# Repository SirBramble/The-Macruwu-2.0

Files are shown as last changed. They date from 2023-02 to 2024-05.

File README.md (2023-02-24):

# The Macruwu
The macro pad for all! (well, at least, if you can understand the Clusterfuck posted here)
The Firmware is based on the Arduino Pico Core by earlephilhower https://github.com/earlephilhower/arduino-pico. 

**This is only a brief overview** The full documentation and instructions can be found in the "Documentation"-folder.

## Components used

I went with the RP2040 based board from seeed studio. It has a fast chip, offers integrated USB support and is only about 6€. However, it has limited GPIO pins. So if you want to build your own, I would recommend using I/O Expanders or something similar. Another option would be to use a raspberry Pi with a RP2040. This Board beaks out most of the RP2040 Pins and has Options for Wi-Fi.

In order to try out different Key switches and keep the Macruwu modular, I decided to use hot swap sockets. They aren’t to expensive, if you order them for AliExpress (about 1\$/10psc). But beware, when soldering. If your board manufacturer decides to give you the shit coating on your Pads, prepare for heavy flux use.

For the I/O Expanders I used the PCA9555 from NXP. They conveniently don’t need a lot of setup and are automatically set to INPUT_PULLUP. The detailed Addressing scheme and co can be found in the Datasheet. But, as per usual nowadays, the I/O expanders are sold out. So, you might want to look for them somewhere else, or find a suitable replacement. But if you can find them, I can recommend the NXP Expanders. They need minimal to no Software Setup and I haven't had a dead one so far.

The level shifter (TXU0104PWR) is a cheap option I got from Mouser. It has 4 channels it can shift and is enough for the two 5V I²C Lines and the neopixel line.

The keyswitches were purchased for AliExpress and some smaller Keyboard parts suppliers. I like clicky switches, so I went for the Gateron greens. However, I cannot recommend them. They sound quite hollow and scratchy. Could maybe fixed with some lube *gigidy*, but it’s not really worth the trouble. 
If you want some really clicky Keyswitches, that will any the hell out of anybody in a 30km Radius, you could go for the Kailh Low profile Chock whites. My, extremely pissed of, fellow student can confirm. However, be aware that they can not be used with relegendable keycaps.
## How to compile

### With the Arduino IDE 2.0
#### Macruwu
First download the Code either from the repo or via the release tab. Put it in a folder and open the ```Macruwu_OS.ino``` file.

In order to compile the Code, you need to install the Arduino Pico core. There is a Tutorial on how to do this on earlephilhowers GitHub. You will also need the Adafruit SPIFlash Library. It can be downloaded via the Library Manager. The rest should be included in the Pico Core.
If you get Library conflicts, I'm afraid you're on you’re own. I somehow got it to compile and haven’t touched my setup since. No Idea why it suddenly worked, but the only thing I can recommend, is to back up your libraries and start fresh.

EDIT: If you get a Library conflict, you may want to look for other Bugs. Sometimes the Arduino IDE shows this message, just to inform you, that it has used a certain Library. However, your Code may not compile due to another error.

Also remember to change the USB Stack to the Adafruit TinyUsb Stack via Tools->USB Stack.
If you want to use the inbuilt Flash as a drive, you also have to allocate Memory under Tools->Flash Size. The first time you allocate Memory, you will have to format it. Just doing it in Windows should be fine.
P.s. The flash drive code is more or less copied from Adafruit. sorry, I was lazy...

#### Bluetuwu
First download the Code either from the repo or via the release tab. Put it in a folder and open the ```Bluetuwu_OS.ino``` file.

To Compile the Code you need to install the ESP32 Arduino Core from Espressif. After you installed this, you can just upload with the standard Settings.

### With PlatformIO
Well... I have no Idea, but let me know, if you find out.

## How to use (isch...)

The Macruwu OS is divided in to several Files for maximum ```'someFuckingShit' is not defined did you mean 'goFuckYourself'?```

### With macroLayout.txt

NOTE: The first time you start the Macruwu, you might have problem, with it crashing. This may be caused by the File not being present in the Flash directory. You may have to disable the ```readFile```-function in the ```Keyboard::init```-function in ```Keyboard.cpp``` and upload the File first. Then reenable the function and it should run.

The Layout can be set with several Commands. ```Layer x: ``` sets the Layer under which the Buttons will be accessible. ```Button x: {string}``` sets the Button and is followed by the string, that will be printed by the keyboard. Remember to leave a space between ```:``` and ```{string}```. This is due to the way that the file gets read. The Character straight after the ```:``` will be ignored.

So far, most characters will be interpreted correctly, however ```<``` and ```>``` have a special Meaning. They press the left and right arrow keys respectively. Verry useful for Macro pads that print code with a lot of Brackets. Other functions have not yet been implemented, but feel free to add them in the ```Keyboard.cpp``` under ```Keyboard::interpet```.

In order to read the file from the Flash in to the Data structure you want to run the ```readFile```-function at least once. I recommend running it once in ```setup()``` and then running it each time the file is changed. this can be done with:
```
if(Macruwu.fsChanged()){
    Macruwu.readFile();
  }
```

In order to run the commands that have been set in the Data structure you will have to run the ```interpret(layer, button)```-function.

### With Hardcoded Mapping
The Keymapping can be set in the ```Mapping.cpp```.

In order to write something over USB, you can use ```Keyboard1.write("something");``` But this only works for most normal characters like letters and sometimes other specialty symbols. You'll have to try it out. Things like Brackets or things that use function keys, will have to be set up manually. This can either be done, by sending the commands via the Tiny USB library directly, or by adding a new function to the Keyboard class. But look through the Keyboard class, as I may add more functions in the future.

**Word of Warning:** If you do not have a US Keyboard, be prepared for some HID Code treasure hunting. I haven’t found a way to change the layout, so you either have to find a Layout and redefine all the keys in the library, or just try and hope you find what you need. If you have a German Keyboard layout set, you can reference the code for some mappings.

## Bugs
Yes

## Further documentation
I recommend reading the documentation by earlephilhower https://github.com/earlephilhower/arduino-pico. It´s a far better than this clusterfuck, but feel free to look through the code.

And in case you didn't read the first 3 lines, you can find more documentation in the "Documentation"-folder.

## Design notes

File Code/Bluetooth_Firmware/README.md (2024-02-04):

# README Bluetooth Firmware

## Compilation instructions

First you will need the esp32 Core by Espressif.

**IMPORTANT:** You need to install Version *2.0.11*. The newer Versions feature a different String type in the *begin* function. This will cause compilation errors.

### Upload settings

In order of appearance:

- **Board:** "XIAO_ESP32C3"
- **USB CDC On Boot:** "Enabled"
- **CPU Frequency** "160MHz (WiFi)"
- **Core Debug Level:** "None"
- **Erase All Flash Before Sketch Upload:** "Disabled"
- **Flash Frequency:** "80MHz"
- **Flash Mode:** "QIO"
- **Flash Size:** "4MB (32Mb)"
- **Partition Scheme:** "Default 4MB with spiffs (1.2MB APP/1.5MB SPIFFS)"
- **Upload Speed:** "921600"

## Config Options

 In ```BleKeyboard bleKeyboard("Macruwu", "FG Labs", 69);``` the *Device Name*, *Manufacturer* and *Initial Battery Level* can be set.

In the ```receiveEvent``` function new/custom I²C commands can be added.

```c
while(Wire.available()){
reportID = Wire.read();
switch(reportID){
  case RID_KEYBOARD:
    tmp->modifiers = Wire.read();
    tmp->keys[0] = Wire.read();
    tmp->keys[1] = Wire.read();
    tmp->keys[2] = Wire.read();
    tmp->keys[3] = Wire.read();
    tmp->keys[4] = Wire.read();
    tmp->keys[5] = Wire.read();
    break;
  case 15:
    softDisableFlag = Wire.read();
    if(softDisableFlag != 0) softDisableFlag = true;
    break;
  default:
    Wire.read();
    break;
}
```

As of creation of the README, 2 functions have been implemented.

- Function 1 (ReportID = 1)
  - Reads a Key report
  - Order:
    - modifier: 1 byte
    - keys: 6 bytes
- Function 2 (ReportID = 15)
  - Sends ESP in to deep sleep
  - This is used to save power, when the Keyboard is connected and registered via USB HID.
- default (ReportID = *none of the above*)
  - voids the I²C buffer

To add a function

- assign a ReportID
- add a new case to the switch

## Troubleshooting

- Macruwu is connected, but doesn't send Keycodes
  1. Unpair Keyboard from Host
  2. power cycle the Keyboard
  3. Re-pair the Keyboard
- Macruwu can't be found
  1. Toggle the power (quick ON/OFF flipping of the power switch)
- ESP stuck in boot loop
  1. Sorry to hear that :(
  2. Make sure the battery board is powered on correctly
     - If the Voltage converter is buzzing, you have a power problem
       - The Battery could be flat (or close to)
       - The board is not turned on properly (use the power toggle switch)
  3. Check the upload parameters
     - Try changing the *Flash Frequency* to *40MHz*

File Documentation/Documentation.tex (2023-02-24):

\documentclass[english, 12pt]{scrartcl}
\usepackage{caladea}
%\usepackage{gfsartemisia-euler}
\usepackage[
a4paper,
left=2.5cm,
right=2.5cm,
top= 2cm,
bottom = 2.5cm,
footskip = 1.5cm
]{geometry}
\usepackage{fancyhdr}
\usepackage[english]{babel}
\usepackage[T1]{fontenc}
\usepackage{graphicx,float}
\graphicspath{ {./images/} }
\usepackage{wrapfig}
\usepackage{caption}
\usepackage{pdfpages}
\usepackage{makecell}
\usepackage{subfiles}
\usepackage{enumitem,amssymb}
\usepackage{lastpage}
%\usepackage{amsmath}
\usepackage{esint}
\usepackage{blindtext}
\usepackage{hyperref}
\hypersetup{
	colorlinks=true,
	linkcolor=black,
	filecolor=magenta,      
	urlcolor=cyan,
	pdftitle={The Macruwu},
	pdfpagemode=FullScreen,
}
\urlstyle{same}
\usepackage[inkscapeformat=png]{svg}
\usepackage{tikz}
\usetikzlibrary{shapes.geometric, arrows}
\usepackage[
% school,
simplified
]{pgf-umlcd}
\usepackage{listings}
\usepackage{color}
\definecolor{listinggray}{gray}{0.92}

\pagestyle{fancy}

\title{\fontfamily{}\selectfont The Macruwu}
\author{Bramble}
\date{}
\begin{document}
	\maketitle
	
	\tableofcontents
	\newpage
	\section{Incentive}
	My handwriting is something any doctor would be proud of. My teachers, however, were not so enamoured with my writing prowess, often deducting grades for sheer illegibility. So when I went to uni, I started taking notes digitally. First, I tried my luck with OneNote and a digital pen, hoping somehow it would improve my notetaking-ability. But when that inevitably failed, I switched to Word. For those who have never tried, writing equations in Word is a pain in the back side. It takes ages and especially when equations get more complex, it's a nightmare to try and get the $e^{x}$ to go, where you want it to go.\\
	So I switched once more.I went for Markdown with inline $L^AT_EX$. Markdown is a markup language that can easily run in a browser and like $L^AT_EX$ it's "what you mean is what you get". It has simple syntax, making it easy to learn, but also supports inline $L^AT_EX$, which is very useful when writing equations. The hoster we (my friends and I) use also supports multiple people working on the same document in real time, which makes taking notes a lot faster and also allows one person to be sketching graphs and the like, while the rest of us try our best to keep up with the professor.\\
	But even with Markdown and multiple people writing at the same time, it just took too long and we sometimes missed some important notes.\\

	\begin{wrapfigure}{r}{0.25\textwidth}
		\vspace{-0.8cm}
		\centering
		
		\caption{Macropad v0.1}
	\end{wrapfigure}
	\noindent One afternoon I therefore cobbled together my first macro pad out of some Cherry switches and a Teensy I had lying around. It was extremely botched and had no fancy features to speak of, but it worked. That got me hooked. Even with just eight extra keys, I was able to write a lot faster. So I went back to the drawing board and started designing what was to become the Macruwu.
	\section{Requirements}
	For this macropad to be of any use to me, it needed to fulfil certain requirements.
	\begin{itemize}
		\item It needed to be compatible with any system. This meant it needed to work, no matter which computer I plugged it in to. This also meant that I couldn't rely on any software that had to be running in the background.
		\item It should be able to type out any key combination that would also be possible on a normal keyboard. This would make it universally useable for practically any software, because almost all software can be controlled easily with shortcuts from a keyboard.
		\item It must not hinder my workflow. This means that using the Macruwu should always be faster than typing out the command or character strings by hand.
		\item It needed to be fast. I wanted as little delay as possible, so that long strings of characters could be printed quickly. For complex equation presets a maximum delay of about 300-400ms would be optimal.
		\item Mappings should be changeable on the fly. If, for example, a certain equation were to show up consistently in the lecture, it should be possible to assign that equation to a key quickly and easily.
		\item It should be expandable. If 32 keys aren't enough or if I want to add some kind of other interface device or expansion module, it should be possible to interface it with the Macruwu.
		\item It MUST have RGB. I could try and think up some reason for why it's necessary to have RGB, but I just want RGB uwu.
		\item It should be affordable. The goal for this project was to stay under 70€ per unit.
		\item It should be repairable. For me this meant, creating options for most kinds of mechanical keyswitches. If a switch breaks or if I want to later replace them with different ones, it should be easy to just rip´em out and stick in some ones.
	\end{itemize}
	\newpage
	\section{Choices of component}
	\subsection{Microcontroller}
	For the microcontroller, I chose the seeed studio RP2040. It´s a small board, even smaller, than a Teensy, but it allows you to configure it as an HID with very little effort. It's also very fast and has a humongous 2MB of flash, which can also be configured as a mountable flash drive. It doesn't have a lot of pins but it does have a number of broken out connections, namely two I$^2$C lines, an SPI bus and even a UART port if you need it. And USB-C is just the cherry on top (no pun intended).\newline
	If you want to learn more, you can check out the \href{https://wiki.seeedstudio.com/XIAO-RP2040/}{Seeed Wiki}. This is good to get you started with the microcontroller, but if you want more information on the programming side, you should check out Earle Philhowers Arduino Pico \href{https://github.com/earlephilhower/arduino-pico}{GitHub} and \href{https://arduino-pico.readthedocs.io/en/latest/}{documentation}.
	
	\subsection{I/O expanders}
	In order to read the keyswitch inputs some kind of I/O expander was needed. I just went for the cheapest I could find on Mouser that was still in stock. It turned out to be the \href{https://www.mouser.de/datasheet/2/302/PCA9555-1127545.pdf}{PCA9555D}, a double 8-bit I/O expander that can be read via I$^2$C. It offers internal pull-up resistors, which was a nice bonus, meaning I didn't have to add them to the design. However, bear in mind that you might have to add some to your design if you want to use a different I/O expander.
	
	\subsection{Level shifter}
	The RP2040 is a 3.3V microcontroller. In order to use 5V logic devices, a level shifter is needed. This is optional, however. If you don't plan on using the NeoPixels or 5V I$^2$C devices, you can just leave it out. At first I used the \href{https://www.ti.com/lit/gpn/txu0104}{TXU0104PWR} which is a unidirectional chip. This works great for the NeoPixels, but won't work for the 5V I$^2$C due to this being a bidirectional protocol. However Texas Instruments offers a pin-equivalent bi-directional chip, the \href{https://www.ti.com/lit/gpn/lsf0204-q1}{LSF0204-Q1}. I haven't tested it so far, but the datasheet indicates that this should be a drop-in replacement.
	
	\subsection{RGB goodness}
	In order to satisfy my endless need for funny blinky lights, I picked up some \href{https://de.aliexpress.com/item/1005003636607308.html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}{SK6803 MINI-Es} from AliExpress. They come in 3mA and 12mA versions. In order to not overtax the USB power, I'd recommend getting the 3mA version. They should be more than bright enough. If you want to burn out your retinas, you can also go for the 12mA version, but bear in mind that you may run into Voltage drops when running them at the full 12mA.\newline
	One of the most useful features of the SK6803 MINI-Es is their ability to be mounted through a cutout in the PCB, making them sit flush with the surface. This allows the use of most switches. They also have a identical addressing scheme to standard NeoPixels and can be controlled by the Adafruit Neopixel library.
	
	\subsection{Hot-swap sockets}
	In order to change keyswitches without having to solder, some sort of hot-swap socket is needed. I chose \href{https://keycapsss.com/keyboard-parts/parts/49/kailh-hotswap-pcb-sockets-10-pcs?c=11}{Kailh hot-swap sockets}. They're easy to solder and work a lot better than the push-in ones you might find on commercial hot-swap boards. They also come in versions for MX- and Choc-style keyswitches.
	
	\subsection{Keyswitches}
	This is pure preference. I love clicky keys, so I went for the clickiest (reasonably priced) keys I could find. The \href{https://de.aliexpress.com/item/32980039972.html}{Gateron greens} are a very affordable option for MX style keys and are quite clicky. If you want maximum click for a bit more cash, you can check out the \href{https://keycapsss.com/switchestester/switches/65/kailh-low-profile-choc-switches?c=9}{Kailh whites}. They provide maximum click and are guaranteed to annoy the living heck out of most sane people. Needless to say I absolutely love them.\newline
	If you prefer not to make everyone within a 30Km radius go completely insane, you can also choose a tactile or linear switch. Both the Gateron and Kailh keys offer those options. If you want to fall in to a very deep rabbit hole, you can also look up keyswitches on YouTube. Trust me, it's worth it.
	
	\subsection{Keycaps}
	Now here there are several options. You can 3D-print your keycaps on a resin printer or print flat ones on an FDM printer and label them afterwards. You can get quite creative with custom keycaps. If you don't want to print your own, \href{https://de.aliexpress.com/item/1005003047698548.html}{relegendable keycaps} are always an option and the one I went for. A printable template for the keycap inlays is in the main GitHub repository.
	
	\subsection{I$^2$C Jacks}
	To connect the Macruwu to other input devices I used a \href{https://keycapsss.com/keyboard-parts/parts/54/2x-trrs-jacks-3.5mm?c=11}{3.5mm 4-pin headphone jack}. This breaks out 3.3V, GND, SCL, SDA and offers the option to use a wide variety of fancy cables.
	\newpage
	\section{Hardware}
	
	\subsection{Full schematics}
	\begin{figure}[H]
		\centering
		
		\caption{Sheet 1 of the Macruwu}
	\end{figure}
	\begin{figure}[H]
		\centering
		
		\caption{Sheet 2 of the Macruwu}
	\end{figure}
	\begin{figure}[H]
		\centering
		
		\caption{PCB frame 1 of the Macruwu}
	\end{figure}
	\begin{figure}[H]
		\centering
		
		\caption{PCB frame 2 of the Macruwu}
	\end{figure}
	\begin{figure}[H]
		\centering
		
		\caption{PCB frame 3 of the Macruwu}
	\end{figure}
	\begin{figure}[H]
		\centering
		
		\caption{PCB frame 4 of the Macruwu}
	\end{figure}
	\begin{figure}[H]
		\centering
		
		\caption{PCB frame 5 of the Macruwu}
	\end{figure}
	
	\subsection{Soldering tips}
	SMD soldering is a pain, but in this case necessary. If you've never soldered SMD before or if it's been a while, here are some tips:
	\begin{itemize}
		\item Start with the smallest components. I'd recommend starting with the SMD capacitors. They're really fiddly, but are good for practice, especially if you haven't soldered SMD before. If you mess up, they're also easy to remove letting you try again. And if you manage to solder all the capacitors, the rest shouldn't be a problem.\newline
		\textbf{NOTE:} When soldering the capacitors, leave out the ones near the ICs and do them later. They might get in the way when soldering the ICs.
		\item When soldering the ICs, start by tinning a single pad. Once you've tinned one pad, heat it up and push the IC in to place. Then you can solder the rest of the connections.
		\item Use flux. It's not strictly necessary but it does help a lot, especially when using lead-free solder. If you find yourself getting a lot of bridges or cold solder joints, give flux a try. It really does help. I personally use the \href{https://www.amazon.de/FELDER-L%C3%B6tfett-L%C3%B6tmittel-Solder-L%C3%B6tpaste/dp/B01822CUO6}{flux paste you get in those small tins} but any flux is better than none.
		\item Have some solder wick lying around. If you find yourself unable to separate a bridge on an IC, you'll want solder wick. Ideally apply some flux to the wick, place it on the solder joints you want to disconnect and press your soldering iron on top. This should pull any unnecessary solder in to the wick.\newline
		\textbf{NOTE:} Don't pull the solder wick around the connection or PCB. This will scrape away the solder mask and may expose or cut traces. I found that out the hard way...
		\item When soldering in the hot-swap sockets and RGB LEDs, make sure they're properly soldered to the board. Ground pads especially tend to result in cold solder joints. Use flux and check your connections with a multimeter. For the hot-swap sockets you can increase the temperature to about 370-400°C, but try not to keep the iron on there for too long if you do. With the LEDs I'd recommend not going above 360°C because if you do, they might break. I haven´t had this happen before, but bear this in mind.
		\item Clean your board after soldering. You can use isopropanol or similar non conducting cleaning liquids. This is to prevent corrosion and general stickiness from the flux.
	\end{itemize}
	
	\section{Macruwu Firmware}
	This firmware is based on Earle Philhowers \href{https://github.com/earlephilhower/arduino-pico}{Arudino Pico} and includes some Adafruit libraries. Therefore, make sure to install them before trying to flash this code.
	\subsection{Structure}
	\textbf{NOTE:} I'm not studying computer science so this diagram may not be up to standard. However, I hope it gives you a brief overview of how the code is structured. This will be updated with code updates (hopefully).\newline
	\begin{minipage}{\linewidth}
		\centering
		\resizebox{0.5\textheight}{!}{\input{Classes/Keyboard}}
	\end{minipage}
	\newline
	\newline
	The basic idea of this code is to divide everything up in to separate modules that interface with one aother. This takes a bit more effort to try and get the separate modules working together, but once it's set up, it's a lot easier to tweak.
	\subsubsection{Layer class}
	OK, so now lets go over the structure and start at the bottom. The \textit{Layer} class has a vector of strings. This stores all the plaintext commands associated with a certain button. So a \textit{Layer}-object has several buttons.
	\subsubsection{Keymap class}
	The \textit{Keymap} class has a vector of \textit{Layer}-objects. A \textit{Keymap}-object thus has several layers consisting of several buttons. You can imagine this as an array or a table, that allows you to look up which command is associated with a certain button on a certain layer.
	\subsubsection{Filesystem' functions}
	The \textit{Keymap} class can also access the file system using the \textit{import()} method. This method pulls the command strings from the \textit{macroLayout.txt}-file stored on the internal file system and saves them in the aforementioned \textit{Layer-Button}-structure.
	\subsubsection{Keyboard class}
	This construct is then controlled by the \textit{Keyboard}-class. This builds an interface for the \textit{main} to access but also introduces some functions of its own. The \textit{Keyboard}-class manages all the HID(human interface device)-commands and also houses the interpreter to convert the command strings to sendable HID key-codes. This is done internally for the most part, but exposes all the relevant interface methods to the main. For example, the \textit{interpret(layer, button)}-method interprets and runs the command stored in the command string at the given layer and button as an HID command.\newline
	\textbf{NOTE:} All HID commands are set to work with a German keyboard layout. Most of them still work with a US or similar layout, but you might have to change some special character keycodes like '\verb=^=' or '\verb=\='.\newline
	Edit: I found a overview of a keyboard with the corresponding key-codes depicted on every key. This should be universal to all Keyboards. May be useful...
	\begin{figure}[H]
		\centering
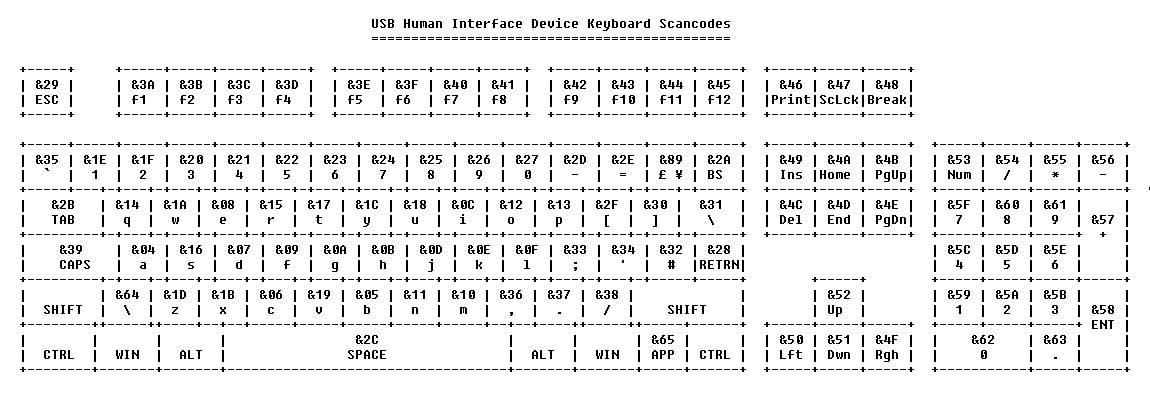
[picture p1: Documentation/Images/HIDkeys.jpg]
		
		\caption{Mapped HID Keys}
	\end{figure}
	
	\noindent There are also other methods included in the class. The \textit{readFile()}-method in combination with the \textit{fsChanged()}-method can auto-update the \textit{Layer-Button}-structure from the \textit{macroLayout.txt}-file whenever the file is edited.
	\subsubsection{NoePixel functions}
	So far not a lot has been done here. These are just a few function prototypes saved in a separate file. \textit{neopixelSetup()} simply initialises the Adafruit library and \textit{testNeopixel()} just runs a slow rainbow-effect.
	\subsubsection{Expander class}
	The \textit{Expander}-class is responsible for reading and debouncing the I/O expanders. The state of any pin on the I/O expander can be accessed via the \textit{getState} method.
	\subsubsection{Mapping module}
	This isn't shown in the diagram and is mainly for debugging and testing. The \textit{Mapping} module is a header and source file combination that creates its own \textit{Keyboard}-object and runs hardcoded sets of instructions when a button is pressed. The function of a certain button can be called from the main via the \textit{action(button)}-function.
	\subsection{AniMacro}
	The AniMacro scripting language (kinda) is used to tell the macropad what to type from the \textit{macroLayout.txt}. This is fully customisable and you can add your own commands in the \textit{Keyboard::interpret()} method if you are so inclined.\\
	The basic structure, however, is set by the \textit{readFile()}-method. With \textit{Layer x:} you set the current layer to x. Follow that with \textit{Button y: something} and you set button \textit{y} on layer \textit{x} to \textit{something}. Every \textit{Layer x:} or \textit{Button y: something} must be followed by a linebreak.\newline
	\textbf{For example:}\newline
	\noindent\fbox{%
		\parbox{\textwidth}{%
			\begin{tabbing}
				Layer 1:\= \\
				\> Button 1: something \\
				\> Button 2: something else \\
				Layer 2:\\
				\> Button 1: something on Layer 2
			\end{tabbing}
		}%
	}\newline
	\subsubsection{Implemented commands}
	\begin{tabular}{|l|m{6.5cm}|m{6.5cm}}
		\hline
		\textbf{Command} & \textbf{Description} & \textbf{Comment}\\
		\hline
		\hline
		\verb=Some text= & No operator prints plain text& \\
		\hline
		\verb=\plain{}= & Prints contents as plain text. Can print characters reserved for AniMacro commands. & Double Brackets \verb={}= will be printed. If the have contents (e.g. \verb={a}=), the plain command chain is broken and returned to the 'no Operator' state.\\
		\hline 
		\verb=<= & Moves screen cursor one step to the left (presses left arrow key) & \\
		\verb=>= & Moves screen cursor one step to the right (presses right arrow key) & \\
		\verb=\n= & Triggers the 'ENTER'-key & \\
		\verb=\t= & Triggers the 'TAB'-key & \\
		\hline
	\end{tabular}\\\\
	Most special characters can also be typed without a special command:\\
	\verb=\ ^ { } [ ] ( ) $ | _ . ,=
	
	\subsection{I$^2$C Expansion Port}
	\noindent
	The I$^2$C expansion port is used to connect peripherals to the Macruwu via a TRRS-jack. It can also be used to connect the Macruwu as a peripheral to another Macruwu. The Pins are as follows:
	\begin{center}
		\begin{tabular}{|c|c|c|c|}
			\hline
			Sleve&Ring 1& Ring 2& Tip\\
			\hline
			GND & SCL 3V3 & SDA 3V3 & 5V\\
			\hline
		\end{tabular}
	\end{center}
	The Macruwu connected to USB is always the main master, so connected devices must be configured as Slaves. However the RP2040 offers a second I²C Port, wich can be configured a slave, so you can daisychain several Macruwus.
	\subsubsection{I²C Structure}
	\textbf{Write:}\\
	\begin{tabular}{|c|c|c|c|c|c|c|c|c|c|c|}
		\hline
		S&Address&1&A&Register/Command&1&A&Data(8-bit)&A&...&E\\
		\hline
	\end{tabular}
	\\\\
	\noindent\textbf{Read:}\\
	\begin{tabular}{|c|c|c|c|c|c|c|c|c|c|c|c|c|c|}
		\hline
		S&Address&1&A&Register/Command&E&S&Address&0&A&Data(8-bit)&A&...&E\\
		\hline
	\end{tabular}
	\\\\
	\textbf{S}: START\\
	\textbf{E}: STOP/END\\
	\textbf{A}: ACK\\
	\\
	\noindent The default Address is 0010 101 and 7-bit wide.
	\subsubsection{Registers/Commands}
	\begin{center}
		\begin{tabular}{|m{0.25\linewidth}|m{0.15\linewidth}|m{0.6\linewidth}|}
			\hline
			Register/Command&Mode&Description\\
			\hline
			0000 0000(0x00)&Read&Get Button Layout config. This will send over The amount of Keys and other Important Information elaborated on in \ref*{Config}.\\
			\hline
			0000 0010(0x02)&Read&Get Inputs. This will return the State on Buttons pressed as a multiple of 8-bit Registers.\\
			\hline
			0000 0100(0x04)&Read&Get Keycodes. This will send Keycodes, modifiers and the Report IDs as 3-byte blocks.\\
			\hline
			0000 0101(0x05)&Write&Send Keycodes. Used for the Bluetooth expansion header to send the parsed Keycodes to the Bluetooth Board.\\
			\hline
			0000 0110(0x06)&Read&Get string to print: This will return a string that can be interpreted by the host Macruwu.\\
			\hline
			0000 0111(0x07)&Write&Send String as a C-String (character array).Used for Bluetooth expansion board if set to Interpreter Mode\\
			\hline
			0100 0000(0x40)&Reserved&Address of I/O Expander. Would cause confusion...\\
			\hline
			0100 0001(0x41)&Reserved&Address of I/O Expander. Would cause confusion...\\
			\hline
			0110 1001(0x69)&Reserved&Address of Bluetooth Module. Would distract the boys...\\
			\hline
		\end{tabular}
	\end{center}
	\subsubsection{Configuration}
	\label{Config}
	\begin{center}
		\begin{tabular}{|m{0.2\linewidth}|m{0.2\linewidth}|m{0.6\linewidth}|}
			\hline
			Data type&Variable&Description\\
			\hline
			\verb=uint8_t=&\verb=ammount_keys=&Key count registered to the expansion device. If this is not used send 0000 0000(0x00)\\
			\hline
			\verb=uint8_t=&\verb=language_set=&Keyboard language set on host. Can be used to set the ASCII to keycode Table in expansion Modules with keycode sending functions. If this is not used send 0000 0000(0x00)\\
			\hline
		\end{tabular}
	\end{center}

	\subsection{Language Codes}
	\begin{center}
		\begin{tabular}{|m{0.2\linewidth}|m{0.2\linewidth}|m{0.6\linewidth}|}
			\hline
			Language Code&Value&Comment\\
			\hline
			GERMAN&0000 0000(0x00)&DEFAULT\\
			\hline
			\verb=ENGLISH_US=&0000 0001(0x01)&\\
			\hline
		\end{tabular}
	\end{center}

	\section{Debugging tips}
	\begin{figure}[H]
		\centering
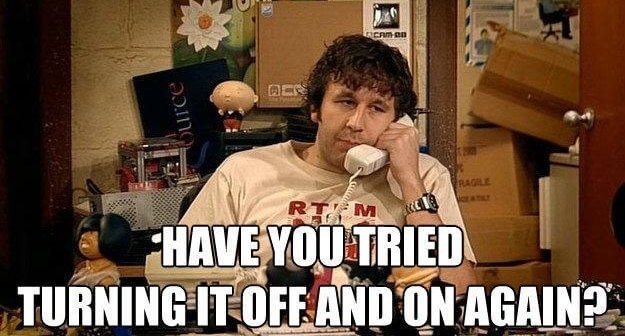
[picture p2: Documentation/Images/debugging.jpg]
		
		\caption{Debugging tips from the IT crowd}
	\end{figure}
	Sometimes the Macruwu gets stuck and cant get out (of an infinite loop or something). Unplugging it and plugging it back in again can help with that and works in 90\% of all cases.\\
	If this does not help, try the tips below.
	\subsection{Compiling firmware}
	\begin{itemize}
		\item Check whether you have the correct version of the Arduino Pico framework installed. I used the newest at the time, which was version 2.6.4.
		\item Also check, that you have the correct libraries installed.
		\subitem Adafruit NeoPixel by Adafruit (1.10.6)
		\subitem Adafruit SPIFlash by Adafruit (4.0.0)
		\subitem SdFat - Adafruit Fork by Bill Greiman (2.2.1)
		\item If you are using Platform I/O or similar, you may have to include files other than the main separately in the compiler config
	\end{itemize}
	\subsection{Microcontroller crashing}
	\begin{itemize}
		\item Try running the \textit{flash\_test()} function in the setup. This will create the \textit{macroLayout.txt} which if missing might cause the microcontroller to crash.
		\item If the microcontroller doesn't get recognised by the computer, try holding down the \textit{BOOT}-button on the microcontroller and while pressing it, plug the microcontroller back in to the computer. It will them show up as a new device, and COM port and you should be able to upload to it.
	\end{itemize}
	\subsection{Filesystem corrupted}
	This can happen, if the \textit{File read} protocol crashed, due to a illegal character in the \textit{macroLayout.txt} file on the flash. If this happens, please open a issue with the character, that caused the crash.\\
	There is a way to 'restore' it though.
	\begin{enumerate}
		\item Unplug the Macruwu and uncomment the \textit{flash\_clear()} command. This will clear the flash partition.
		\item Hold the \textit{BOOT} button (the on on the right) on the RP2040 and plug it in while pressing the button. This will manually set the microcontroller in to programming mode.
		\item Select the newly appeared COM port and press upload. You may have to restart the Arduino IDE several times throughout this process, if it is stuck in a infinite upload loop. Don´t worry, this will not break anything.
		\item Once uploaded, a new drive should show up. If you are under Windows you will be prompted to format the disc.
		\item Once formatted, you can upload a backup of the \textit{macroLayout.txt} or create a new one. DO NOT UNPLUG THE MACRUWU!
		\item Go to the Arduino IDE and comment or delete the \textit{flash\_clear()} command.
		\item Select the correct COM port and press upload. If the Arduino IDE is stuck in a infinite upload loop, restart the IDE. 
		\item It should be working normally again.
	\end{enumerate}
	\subsection{NeoPixels not working}
	\begin{itemize}
		\item Check the solder connections. If the NeoPixels are not properly soldered on to the pads they will not work. Even one improperly soldered NeoPixel may cause the others to act funny. I recommend checking each connection with a multimeter, by connecting one probe to $GND$ or $5V$ respectively and going through the respective pins on the NeoPixels with the other.
		\item If $5V$ and $GND$ are connected correctly, but you are still having trouble, check the connection between the Neopixels. $D_{out}$ of one and $D_{in}$ of the next in the chain should always be connected.
	\end{itemize}
	\subsection{I/O expanders not working}
	\begin{itemize}
		\item Check the solder connections
		\item Make sure your I/O Expanders have internal pull-up resistors. If they do not, they will not work with the Macruwu board. If you have your own board, you can also add them on the PCB, however, I did not do that with mine.
		\item Make sure you have set the correct address. The Base address can be found in the datasheet of the I/O expander and the variable address pars can be found in the Macruwu schematic. If you are using the same I/O listed in the materials section, the preset address should be correct.
		\item If you are using different I/O expanders from the ones listed in the materials section, make sure the I$^2$C addressing scheme is correct. Other I/O expanders may need to be configured differently from the ones I used. If it turns out that you do need a setup sequence for your I/O expanders, you can create a \textit{init()} method in the \textit{Expander} class and call it in the \textit{setup()}.
	\end{itemize}
	\subsection{some buttons are not being recognised}
	\begin{itemize}
		\item Check the solder connections on the hot-swap sockets. They tend to form cold solder joints, that you may not always see. Especially the GND pad tends to do this. Check the connection with a multimeter by holding one probe to a known GND and going through the other connections with the other probe. The same can be done for the other side of the socket. Hold one probe on the socket and the other on the corresponding I/O expander pin.
		\item Make sure the key switch is installed correctly. The pins do tend to bend when pressing them in. you can check from the underside of the board, if the pin is seated in the hot-swap socket. If not, pull it out, straighten out the pin with a pair of pliers and press it back in.
	\end{itemize}
	If none of the above helped, fell free to contact me.\\
	Discord: Bramble\#2342
\end{document}

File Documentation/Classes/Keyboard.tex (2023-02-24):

\begin{tikzpicture}
	\begin{class}{main}{9,-9}
	\end{class}
	
	\begin{class}[text width = 17cm]{Keyboard}{-4 ,0}
		\inherit{main}
		\attribute{- ammountLayers : int}
		\attribute{- ammountKeys : int}
		\attribute{- modifier : uint8\_t}
		\attribute{- report\_id : uint8\_t = 0}
		\attribute{- sendString : String}
		\attribute{- filename : String}
		\attribute{- buffer[6] : uint8\_t = {0}}
		\attribute{- bufferSetFlag : bool}
		\attribute{- keymap\_ptr : Keymap *}
		\operation{- send(uint8\_t mod = 0) : void}
		\operation{- isLetterSmall(char c) : bool}
		\operation{- clearBuffer(void) : void}
		\operation{- setBuffer(uint8\_t index, uint8\_t value) : void}
		\operation{- bufferClear(void) : bool}
		\operation{+ Keyboard(String filename = "macroLayout.txt", int ammountLayers = 5, 	int ammountkeys = 32)}
		\operation{+ init(void) : void}
		\operation{+ get\_string\_from\_file(int layer, int button) : String}
		\operation{+ set\_string\_in\_file(int layer, int button, String string\_to\_write) 	: void}
		\operation{+ readFile(void) : void}
		\operation{+ interpret(int layer, int button) : void}
		\operation{+ write(String text) : void}
		\operation{+ backslash(void) : void}
		\operation{+ goLeft(uint8\_t ammount) : void}
		\operation{+ goRight(uint8\_t ammount) : void}
		\operation{+ brackets(bool goToMiddle = 0) : void}
		\operation{+ bracketsSquare(bool goToMiddle) : void}
		\operation{+ writeKeycode(uint8\_t Keycode, uint8\_t Modifier = 0) : void}
		\operation{+ fsChanged(void) : void}
	\end{class}

	\begin{class}{nopixel}{17,0}
		\inherit{main}
		\operation{+ neopixelSetup() : void}	
		\operation{+ testNeopixel() : void}
	\end{class}
	
	\begin{class}[text width = 7cm]{Expander}{17,-5}
		\inherit{main}
		\attribute{- address : uint8\_t}
		\attribute{- state[16] : uint8\_t}
		\attribute{- state\_prev[16] : uint8\_t}
		\attribute{- state\_db[16] : uint8\_t}
		\attribute{- input\_reg[2] : uint8\_t}
		\attribute{- db\_time\_prev : uint64\_t = millis()}
		\operation{- splice() : void}
		\operation{- debounce() : bool}
		\operation{+ Expander(uint8\_t address\_get)}
		\operation{+ getState(uint8\_t pin) : bool}
		\operation{+ update() : void}
	\end{class}
	\begin{class}[text width = 10cm]{filesystem}{-7,-17}
		\inherit{Keyboard}
		\operation{+ flash\_setup() : void}
		\operation{+ flash\_loop() : void}
		\operation{+ flash\_test() : void}
		\operation{+ check\_fs\_changed() : bool}
		\operation{+ set\_fs\_changed(bool fs\_changend\_in) : void}
	\end{class}

	\begin{class}[text width = 13.5cm]{Keymap}{7,-17}
		\inherit{Keyboard}
		\inherit{filesystem}
		\attribute{- Layers : vector <Layer>}
		\attribute{- currentLayer : int}
		\attribute{- ammountLayers : int}
		\attribute{- ammountKeys : int}
		\attribute{- filename : String}
		\operation{- getNum(String tmp) : int}
		\operation{- getString(String tmp) : String}
		\operation{+ Keymap(String filname, int ammountLayers, int ammountKeys)}
		\operation{+ init(void) : void}
		\operation{+ import(void) : void}
		\operation{+ get(int indexLayer, int indexButton) : String}
		\operation{+ set(int indexLayer, int indexButton, String funktion\_string) : void}
	\end{class}

	\begin{class}[text width = 7cm]{Layer}{7,-28}
		\inherit{Keymap}
		\attribute{- Button : vector <String>}
		\operation{+ Layer(int ammountKeys)}
		\operation{set(int indexButton, String funktionString) : void}
		\operation{get(int indexButton) : String}
	\end{class}

\end{tikzpicture}

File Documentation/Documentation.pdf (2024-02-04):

## The Macruwu

## Bramble

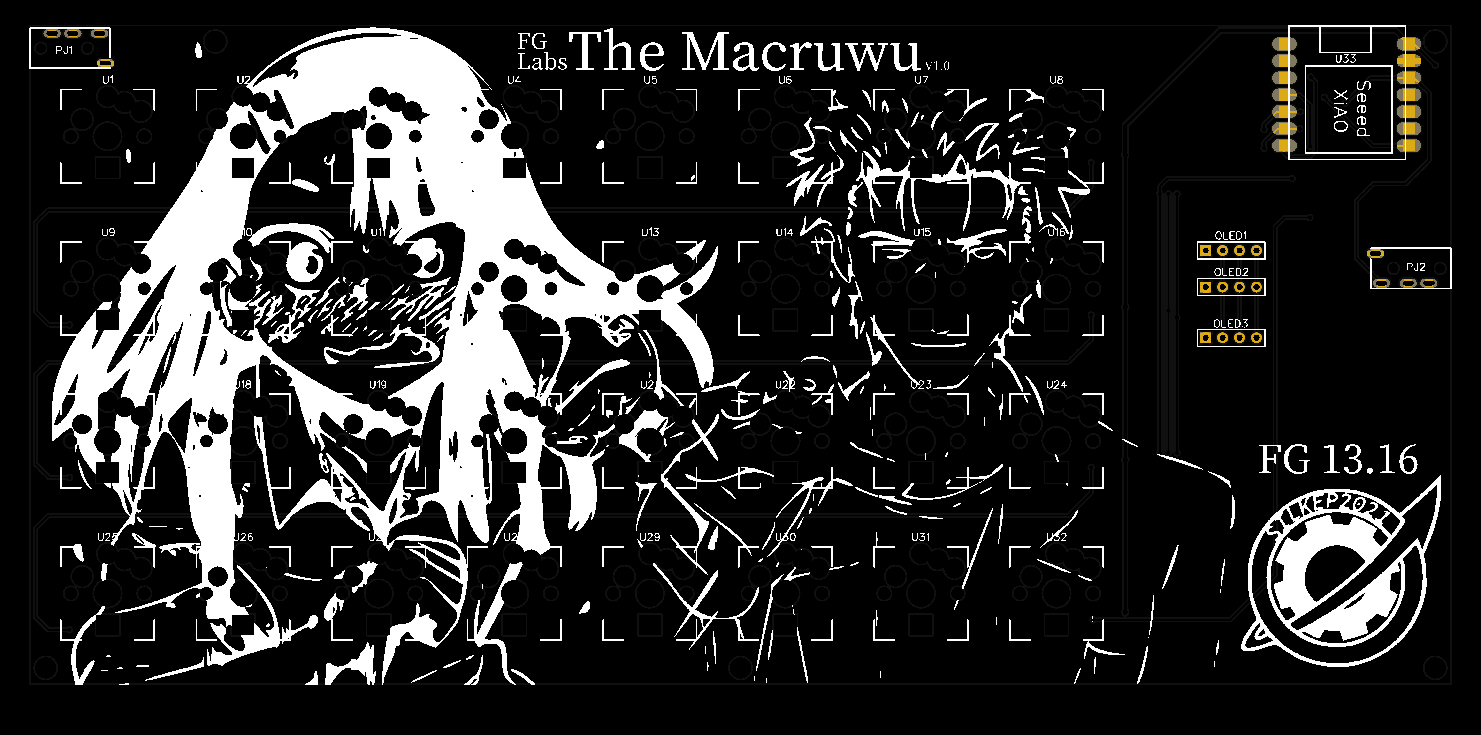
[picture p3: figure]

## Contents

1 Incentive | 3
2 Requirements | 3
3 Choices of component | 5
4 Hardware | 7
5 Macruwu Firmware | 11

Contents | Contents
6 Debugging tips | 15

2 REQUIREMENTS

## 1 Incentive

My handwriting is something any doctor would be proud of. My teachers, however, were not so enamoured with my writing prowess, often deducting grades for sheer illegibility. So when I went to uni, I started taking notes digitally. First, I tried my luck with OneNote and a digital pen, hoping somehow it would improve my notetaking-ability. But when that inevitably failed, I switched to Word. For those who have never tried, writing equations in Word is a pain in the back side. It takes ages and especially when equations get more complex, it’s a nightmare to try and get the e

x
to go, where you want it to go. So I switched once more.I went for Markdown with inline L

ATEX. Markdown is a markup language that can easily run in a browser and like L

ATEX it’s "what you mean is what you get". It has simple syntax, making it easy to learn, but also supports inline L

ATEX, which
is very useful when writing equations. The hoster we (my friends and I) use also supports multiple people working on the same document in real time, which makes taking notes a lot faster and also allows one person to be sketching graphs and the like, while the rest of us try our best to keep up with the professor.
But even with Markdown and multiple people writing at the same time, it just took too long and we sometimes missed some important notes.

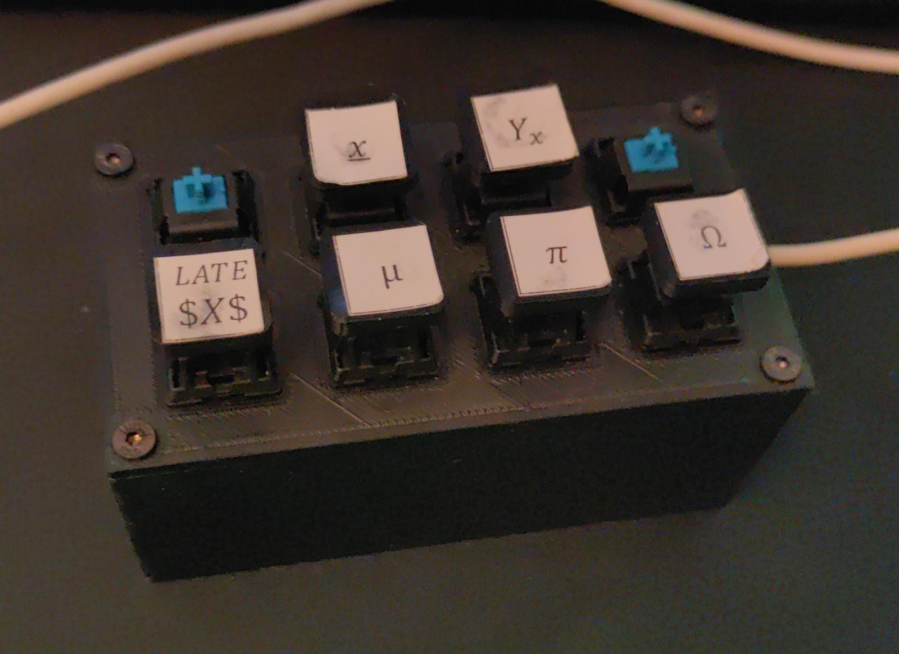
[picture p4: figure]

Figure 1: Macropad
v0.1

One afternoon I therefore cobbled together my first macro pad out of some Cherry switches and a Teensy I had lying around. It was extremely botched and had no fancy features to speak of, but it worked. That got me hooked. Even with just eight extra keys, I was able to write a lot faster. So I went back to the drawing board and started designing what was to become the Macruwu.

## 2 Requirements

For this macropad to be of any use to me, it needed to fulfil certain
requirements.
- It needed to be compatible with any system. This meant it needed to work, no matter which computer I plugged it in to. This also meant that I couldn’t rely on any software that had to be running in the background.
- It should be able to type out any key combination that would also be possible on a normal keyboard. This would make it universally useable for practically any software, because almost all software can be controlled easily with shortcuts from a keyboard.
- It must not hinder my workflow. This means that using the Macruwu should always be faster than typing out the command or character strings by hand.
- It needed to be fast. I wanted as little delay as possible, so that long strings of characters could be printed quickly. For complex equation presets a maximum delay of about 300-400ms would be optimal.
- Mappings should be changeable on the fly. If, for example, a certain equation were to show up consistently in the lecture, it should be possible to assign that equation to a key quickly and easily.

2 REQUIREMENTS

- It should be expandable. If 32 keys aren’t enough or if I want to add some kind of other interface device or expansion module, it should be possible to interface it with the Macruwu.
- It MUST have RGB. I could try and think up some reason for why it’s necessary to have RGB, but I just want RGB uwu.
- It should be affordable. The goal for this project was to stay under 70€ per unit.
- It should be repairable. For me this meant, creating options for most kinds of mechanical keyswitches. If a switch breaks or if I want to later replace them with different ones, it should be easy to just rip´em out and stick in some ones.

3 CHOICES OF COMPONENT

## 3 Choices of component

### 3.1 Microcontroller

For the microcontroller, I chose the seeed studio RP2040. It´s a small board, even smaller, than a Teensy, but it allows you to configure it as an HID with very little effort. It’s also very fast and has a humongous 2MB of flash, which can also be configured as a mountable flash drive. It doesn’t have a lot of pins but it does have a number of broken out connections, namely two I²C lines, an SPI bus and even a UART port if you need it. And USB-C is just the cherry on top (no pun intended).
If you want to learn more, you can check out the Seeed Wiki. (https://wiki.seeedstudio.com/XIAO-RP2040/) This is good to get you started with the microcontroller, but if you want more information on the programming side, you should check out Earle Philhowers Arduino Pico GitHub (https://github.com/earlephilhower/arduino-pico) and documentation. (https://arduino-pico.readthedocs.io/en/latest/)

### 3.2 I/O expanders

In order to read the keyswitch inputs some kind of I/O expander was needed. I just went for the cheapest I could find on Mouser that was still in stock. It turned out to be the PCA9555D, (https://www.mouser.de/datasheet/2/302/PCA9555-1127545.pdf) a double 8-bit I/O expander that can be read via I²C. It offers internal pull-up resistors, which was a nice bonus, meaning I didn’t have to add them to the design. However, bear in mind that you might have to add some to your design if you want to use a different I/O expander.

### 3.3 Level shifter

The RP2040 is a 3.3V microcontroller. In order to use 5V logic devices, a level shifter is needed. This is optional, however. If you don’t plan on using the NeoPixels or 5V I²C devices, you can just leave it out. At first I used the TXU0104PWR (https://www.ti.com/lit/gpn/txu0104) which is a unidirectional chip. This works great for the NeoPixels, but won’t work for the 5V I²C due to this being a bidirectional protocol. However Texas Instruments offers a pin-equivalent bi-directional chip, the LSF0204-Q1. (https://www.ti.com/lit/gpn/lsf0204-q1) I haven’t tested it so far, but the datasheet indicates that this should be a drop-in replacement.

### 3.4 RGB goodness

In order to satisfy my endless need for funny blinky lights, I picked up some SK6803 MINI-Es (https://de.aliexpress.com/item/1005003636607308.html) from AliExpress. They come in 3mA and 12mA versions. In order to not overtax the USB power, I’d recommend getting the 3mA version. They should be more than bright enough. If you want to burn out your retinas, you can also go for the 12mA version, but bear in mind that you may run into Voltage drops when running them at the full 12mA.
One of the most useful features of the SK6803 MINI-Es is their ability to be mounted through a cutout in the PCB, making them sit flush with the surface. This allows the use of most switches. They also have a identical addressing scheme to standard NeoPixels and can be controlled by the Adafruit Neopixel library.

### 3.5 Hot-swap sockets

In order to change keyswitches without having to solder, some sort of hot-swap socket is needed. I chose Kailh hot-swap sockets. (https://keycapsss.com/keyboard-parts/parts/49/kailh-hotswap-pcb-sockets-10-pcs?c=11) They’re easy to solder and work a lot better

3.6 Keyswitches | 3 CHOICES OF COMPONENT

than the push-in ones you might find on commercial hot-swap boards. They also come in versions for MX- and Choc-style keyswitches.

### 3.6 Keyswitches

This is pure preference. I love clicky keys, so I went for the clickiest (reasonably priced) keys I could find. The Gateron greens (https://de.aliexpress.com/item/32980039972.html) are a very affordable option for MX style keys and are quite clicky. If you want maximum click for a bit more cash, you can check out the Kailh whites. (https://keycapsss.com/switchestester/switches/65/kailh-low-profile-choc-switches?c=9) They provide maximum click and are guaranteed to annoy the living heck out of most sane people. Needless to say I absolutely love them.
If you prefer not to make everyone within a 30Km radius go completely insane, you can also choose a tactile or linear switch. Both the Gateron and Kailh keys offer those options. If you want to fall in to a very deep rabbit hole, you can also look up keyswitches on YouTube. Trust me, it’s worth it.

### 3.7 Keycaps

Now here there are several options. You can 3D-print your keycaps on a resin printer or print flat ones on an FDM printer and label them afterwards. You can get quite creative with custom keycaps. If you don’t want to print your own, relegendable keycaps (https://de.aliexpress.com/item/1005003047698548.html) are always an option and the one I went for. A printable template for the keycap inlays is in the main GitHub repository.

### 3.8 I²C Jacks

To connect the Macruwu to other input devices I used a 3.5mm 4-pin headphone jack. (https://keycapsss.com/keyboard-parts/parts/54/2x-trrs-jacks-3.5mm?c=11) This breaks out 3.3V, GND, SCL, SDA and offers the option to use a wide variety of fancy cables.

## 4 Hardware

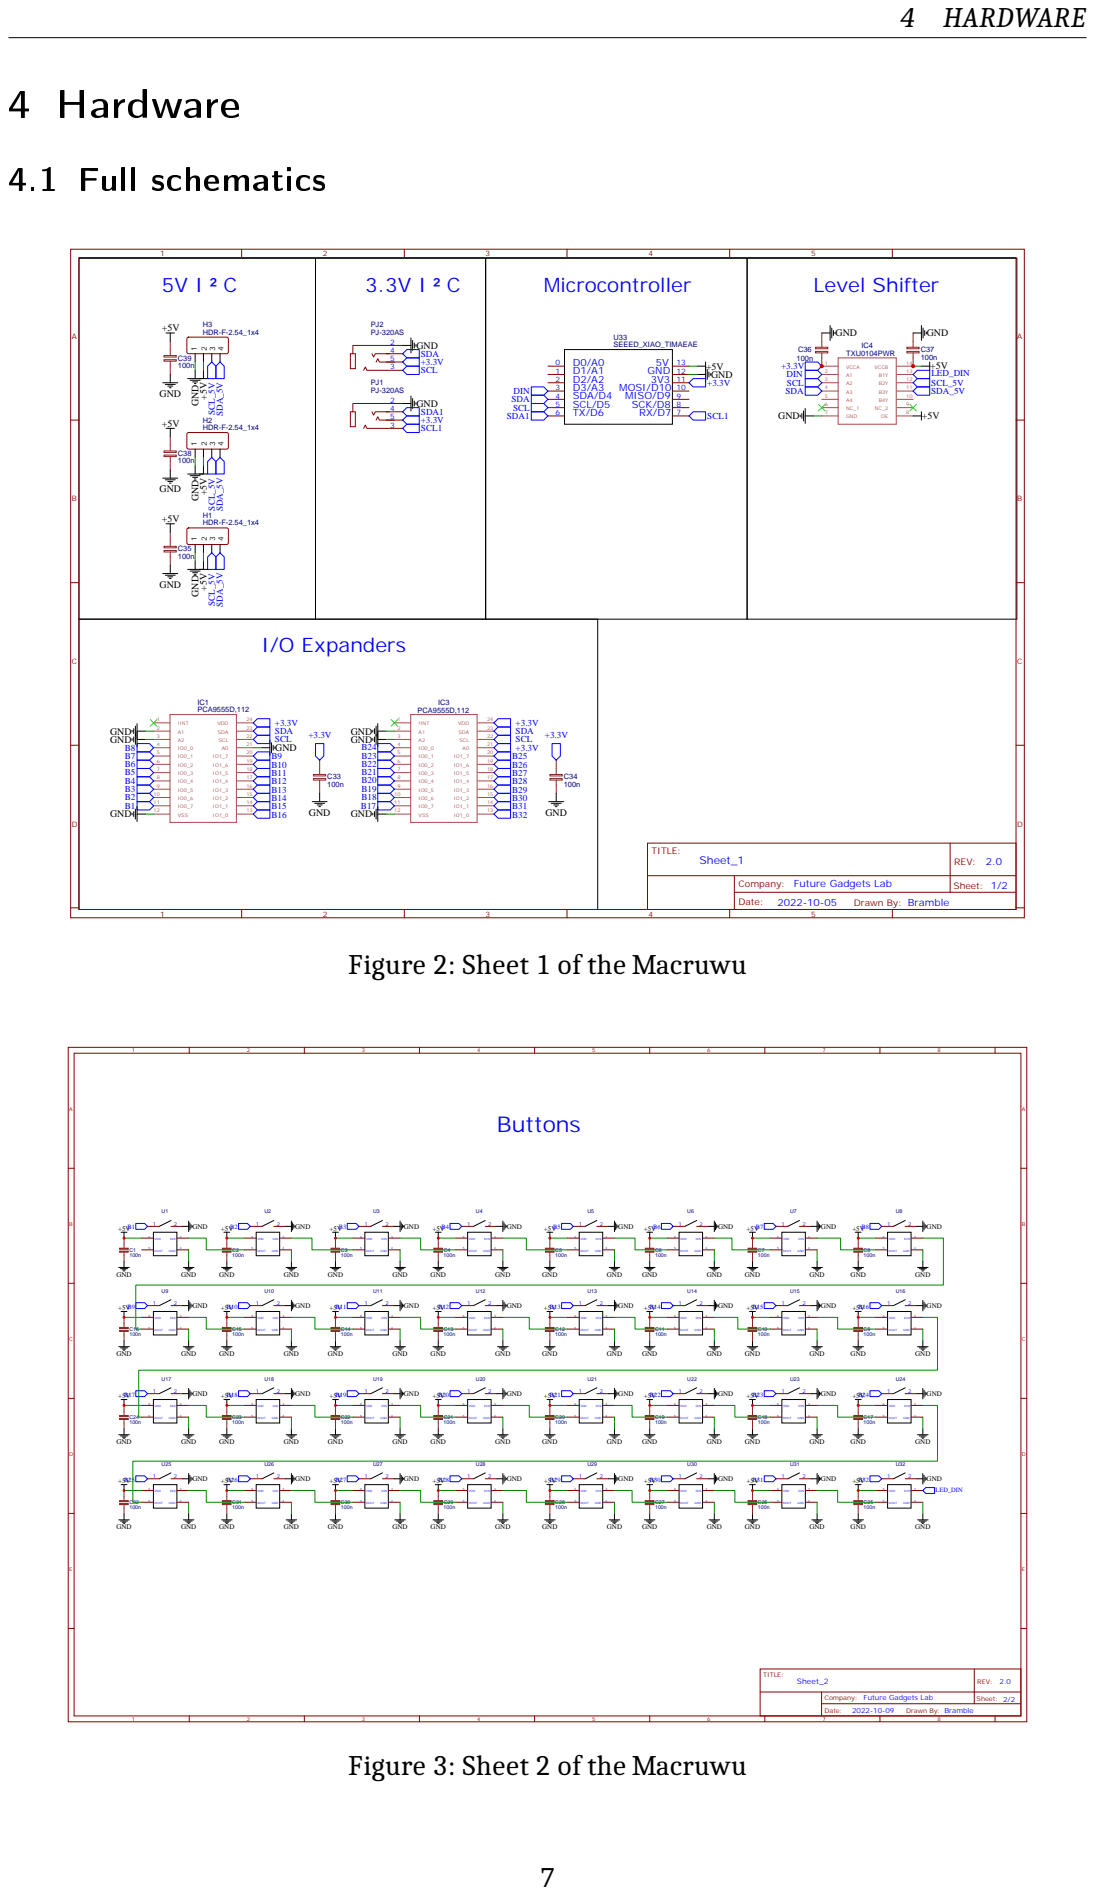
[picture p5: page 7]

Company: Future Gadgets Lab

Figure 2: Sheet 1 of the Macruwu

Figure 3: Sheet 2 of the Macruwu

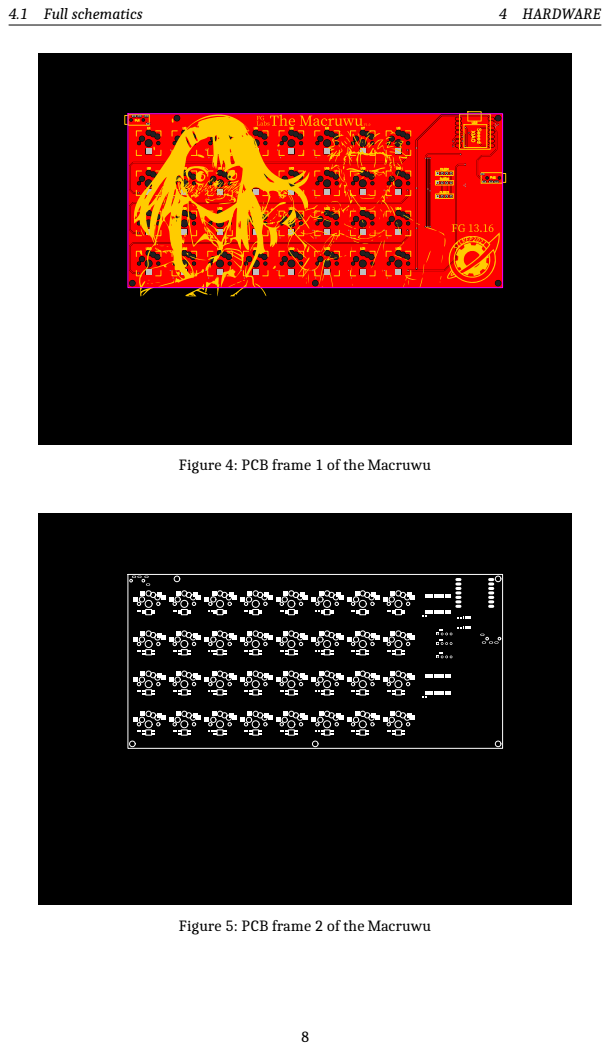
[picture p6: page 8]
4.1 Full schematics; 4 HARDWARE

Figure 4: PCB frame 1 of the Macruwu

Figure 5: PCB frame 2 of the Macruwu

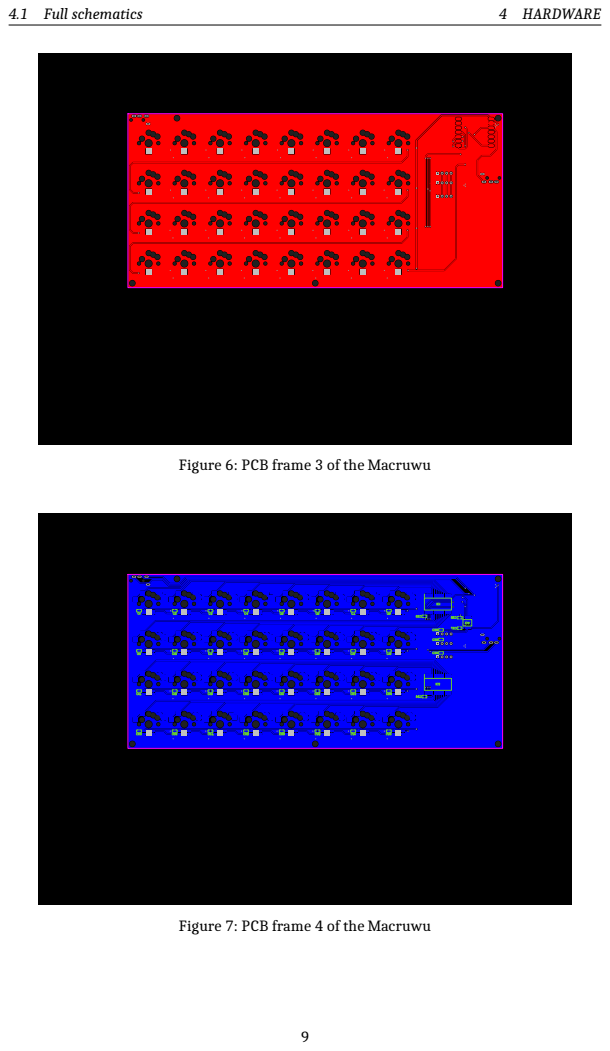
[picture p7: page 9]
4.1 Full schematics; 4 HARDWARE

Figure 6: PCB frame 3 of the Macruwu

Figure 7: PCB frame 4 of the Macruwu

4.2 Soldering tips | 4 HARDWARE

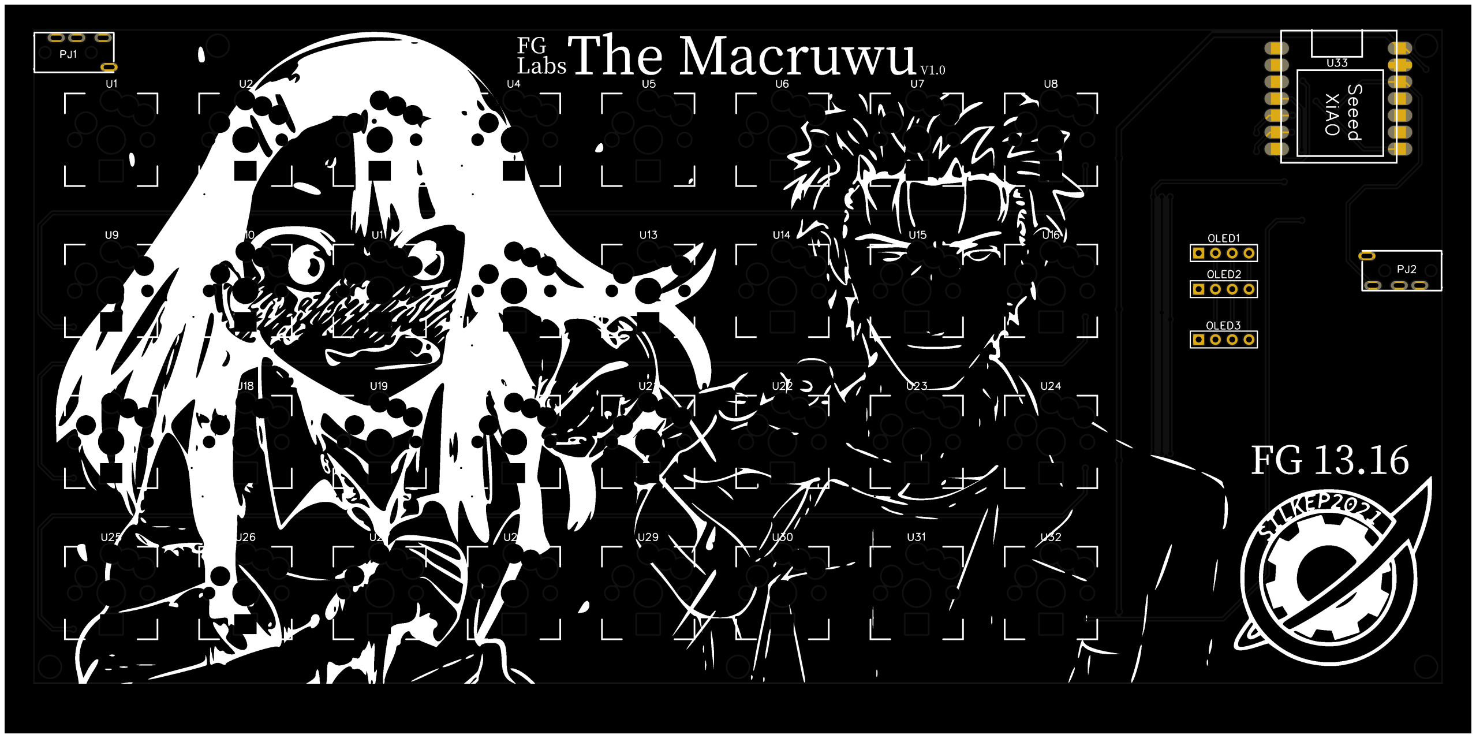
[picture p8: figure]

Figure 8: PCB frame 5 of the Macruwu

### 4.2 Soldering tips

SMD soldering is a pain, but in this case necessary. If you’ve never soldered SMD before or if it’s been a while, here are some tips:

- Start with the smallest components. I’d recommend starting with the SMD capacitors. They’re really fiddly, but are good for practice, especially if you haven’t soldered SMD before. If you mess up, they’re also easy to remove letting you try again. And if you manage to solder all the capacitors, the rest shouldn’t be a problem.
NOTE: When soldering the capacitors, leave out the ones near the ICs and do them later. They might get in the way when soldering the ICs.
- When soldering the ICs, start by tinning a single pad. Once you’ve tinned one pad, heat it up and push the IC in to place. Then you can solder the rest of the connections.
- Use flux. It’s not strictly necessary but it does help a lot, especially when using leadfree solder. If you find yourself getting a lot of bridges or cold solder joints, give flux a try. It really does help. I personally use the flux paste you get in those small tins (https://www.amazon.de/FELDER-L%C3%B6tfett-L%C3%B6tmittel-Solder-L%C3%B6tpaste/dp/B01822CUO6) but any flux is better than none.
- Have some solder wick lying around. If you find yourself unable to separate a bridge on an IC, you’ll want solder wick. Ideally apply some flux to the wick, place it on the solder joints you want to disconnect and press your soldering iron on top. This should pull any unnecessary solder in to the wick.
NOTE:Don’t pull the solder wick around the connection or PCB. This will scrape away the solder mask and may expose or cut traces. I found that out the hard way...
- When soldering in the hot-swap sockets and RGB LEDs, make sure they’re properly soldered to the board. Ground pads especially tend to result in cold solder joints. Use flux and check your connections with a multimeter. For the hot-swap sockets you can increase the temperature to about 370-400°C, but try not to keep the iron on there for too long if you do. With the LEDs I’d recommend not going above 360°C because if you do, they might break. I haven´t had this happen before, but bear this in mind.
- Clean your board after soldering. You can use isopropanol or similar non conducting cleaning liquids. This is to prevent corrosion and general stickiness from the flux.

5 MACRUWU FIRMWARE

## 5 Macruwu Firmware

This firmware is based on Earle Philhowers Arudino Pico (https://github.com/earlephilhower/arduino-pico) and includes some Adafruit libraries. Therefore, make sure to install them before trying to flash this code.

### 5.1 Structure

NOTE: I’m not studying computer science so this diagram may not be up to standard. However, I hope it gives you a brief overview of how the code is structured. This will be updated with code updates (hopefully).

main

Keyboard

- ammountLayers : int
- ammountKeys : int
- modifier : uint8_t
- report_id : uint8_t = 0
- sendString : String
- filename : String
- buffer[6] : uint8_t = 0
- bufferSetFlag : bool
- keymap_ptr : Keymap *
- send(uint8_t mod = 0) : void
- isLetterSmall(char c) : bool
- clearBuffer(void) : void
- setBuffer(uint8_t index, uint8_t value) : void
- bufferClear(void) : bool
+ Keyboard(String filename = "macroLayout.txt", int ammountLayers = 5, int ammountkeys = 32)
+ init(void) : void
+ get_string_from_file(int layer, int button) : String
+ set_string_in_file(int layer, int button, String string_to_write) : void + readFile(void) : void
+ interpret(int layer, int button) : void
+ write(String text) : void
+ backslash(void) : void
+ goLeft(uint8_t ammount) : void
+ goRight(uint8_t ammount) : void
+ brackets(bool goToMiddle = 0) : void
+ bracketsSquare(bool goToMiddle) : void
+ writeKeycode(uint8_t Keycode, uint8_t Modifier = 0) : void + fsChanged(void) : void

nopixel

+ neopixelSetup() : void
+ testNeopixel() : void

Expander

- address : uint8_t
- state[16] : uint8_t
- state_prev[16] : uint8_t
- state_db[16] : uint8_t
- input_reg[2] : uint8_t
- db_time_prev : uint64_t = millis()
- splice() : void
- debounce() : bool
+ Expander(uint8_t address_get) + getState(uint8_t pin) : bool
+ update() : void

filesystem

+ flash_setup() : void
+ flash_loop() : void
+ flash_test() : void
+ check_fs_changed() : bool
+ set_fs_changed(bool fs_changend_in) : void

Keymap

- Layers : vector <Layer>
- currentLayer : int
- ammountLayers : int
- ammountKeys : int
- filename : String
- getNum(String tmp) : int
- getString(String tmp) : String
+ Keymap(String filname, int ammountLayers, int ammountKeys) + init(void) : void
+ import(void) : void
+ get(int indexLayer, int indexButton) : String
+ set(int indexLayer, int indexButton, String funktion_string) : void

Layer

- Button : vector <String>

+ Layer(int ammountKeys)
set(int indexButton, String funktionString) : void
get(int indexButton) : String
The basic idea of this code is to divide everything up in to separate modules that interface with one aother. This takes a bit more effort to try and get the separate modules working together, but once it’s set up, it’s a lot easier to tweak.

5.1.1 Layer class

OK, so now lets go over the structure and start at the bottom. The Layer class has a vector of strings. This stores all the plaintext commands associated with a certain button. So a Layer-object has several buttons.

5.1.2 Keymap class

The Keymap class has a vector of Layer-objects. A Keymap-object thus has several layers consisting of several buttons. You can imagine this as an array or a table, that allows you to look up which command is associated with a certain button on a certain layer.

5.1 Structure | 5 MACRUWU FIRMWARE

5.1.3 Filesystem' functions

The Keymap class can also access the file system using the import() method. This method pulls the command strings from the macroLayout.txt-file stored on the internal file system and saves them in the aforementioned Layer-Button-structure.

5.1.4 Keyboard class

This construct is then controlled by the Keyboard-class. This builds an interface for the main to access but also introduces some functions of its own. The Keyboard-class manages all the HID(human interface device)-commands and also houses the interpreter to convert the command strings to sendable HID key-codes. This is done internally for the most part, but exposes all the relevant interface methods to the main. For example, the interpret(layer, button)-method interprets and runs the command stored in the command string at the given layer and button as an HID command.
NOTE: All HID commands are set to work with a German keyboard layout. Most of them still work with a US or similar layout, but you might have to change some special character keycodes like ’^’ or ’\’.
Edit: I found a overview of a keyboard with the corresponding key-codes depicted on every key. This should be universal to all Keyboards. May be useful...

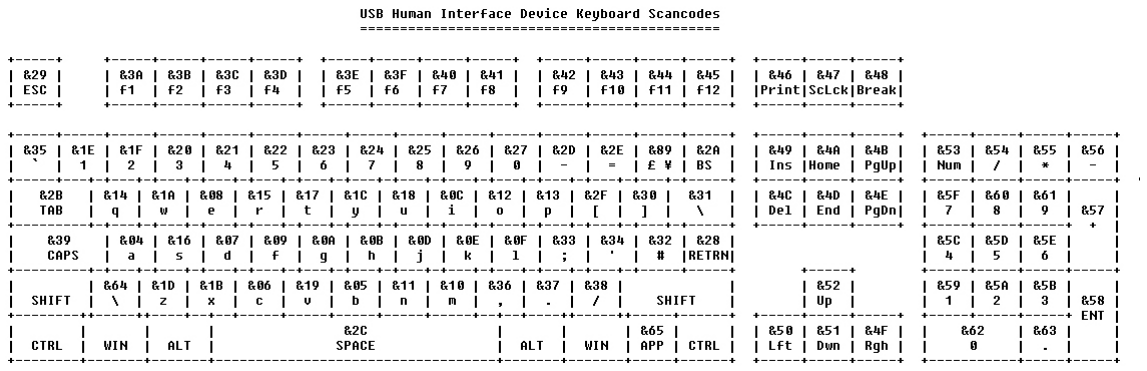
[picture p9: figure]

Figure 9: Mapped HID Keys

There are also other methods included in the class. The readFile()-method in combination with the fsChanged()-method can auto-update the Layer-Button-structure from the macro-Layout.txt-file whenever the file is edited.

5.1.5 NoePixel functions

So far not a lot has been done here. These are just a few function prototypes saved in a separate file. neopixelSetup() simply initialises the Adafruit library and testNeopixel() just runs a slow rainbow-effect.

5.1.6 Expander class

The Expander-class is responsible for reading and debouncing the I/O expanders. The state of any pin on the I/O expander can be accessed via the getState method.

5.2 AniMacro | 5 MACRUWU FIRMWARE

5.1.7 Mapping module

This isn’t shown in the diagram and is mainly for debugging and testing. The Mapping module is a header and source file combination that creates its own Keyboard-object and runs hardcoded sets of instructions when a button is pressed. The function of a certain button can be called from the main via the action(button)-function.

### 5.2 AniMacro

The AniMacro scripting language (kinda) is used to tell the macropad what to type from the macroLayout.txt. This is fully customisable and you can add your own commands in the Keyboard::interpret() method if you are so inclined.
The basic structure, however, is set by the readFile()-method. With Layer x: you set the current layer to x. Follow that with Button y: something and you set button y on layer x to something. Every Layer x: or Button y: something must be followed by a linebreak.
For example:

Layer 1:
Button 1: something
Button 2: something else
Layer 2:
Button 1: something on Layer 2

5.2.1 Implemented commands

Command | Description | Comment
Some text | No operator prints plain text
\plain{} | Prints contents as plain text. Can
| print characters reserved for Ani-
| Macro commands. | Double Brackets {} will be printed.
| | If the have contents (e.g. {a}), the
| | plain command chain is broken and
| | returned to the ’no Operator’ state.
< | Moves screen cursor one step to the
| left (presses left arrow key)
> | Moves screen cursor one step to the
| right (presses right arrow key)
\n | Triggers the ’ENTER’-key
\t | Triggers the ’TAB’-key

Most special characters can also be typed without a special command:
\ ^ { } [ ] ( ) $ | _ . ,

### 5.3 I²C Expansion Port

The I²C expansion port is used to connect peripherals to the Macruwu via a TRRS-jack. It can also be used to connect the Macruwu as a peripheral to another Macruwu. The Pins are as follows:

Sleve | Ring 1 | Ring 2 | Tip
GND | SCL 3V3 | SDA 3V3 | 5V

5.3 I²C Expansion Port | 5 MACRUWU FIRMWARE

The Macruwu connected to USB is always the main master, so connected devices must be configured as Slaves. However the RP2040 offers a second I²C Port, wich can be configured a slave, so you can daisychain several Macruwus.

5.3.1 I²C Structure

Write:
S | Address | 1 | A | Register/Command | 1 | A | Data(8-bit) | A | ... | E

Read:
S | Address | 1 | A | Register/Command | E | S | Address | 0 | A | Data(8-bit) | A | ... | E

S: START
E: STOP/END
A: ACK

The default Address is 0010 101 and 7-bit wide.

5.3.2 Registers/Commands

Register/Command | Mode | Description
0000 0000(0x00) | Read | Get Button Layout config. This will send over The amount of Keys and other Important Information elab-orated on in 5.3.3.
0000 0010(0x02) | Read | Get Inputs. This will return the State on Buttons pressed as a multiple of 8-bit Registers.
0000 0100(0x04) | Read | Get Keycodes. This will send Keycodes, modifiers and the Report IDs as 3-byte blocks.
0000 0101(0x05) | Write | Send Keycodes. Used for the Bluetooth expansion header to send the parsed Keycodes to the Bluetooth Board.
0000 0110(0x06) | Read | Get string to print: This will return a string that can be interpreted by the host Macruwu.
0000 0111(0x07) | Write | Send String as a C-String (character array).Used for Bluetooth expansion board if set to Interpreter Mode
0100 0000(0x40) | Reserved | Address of I/O Expander. Would cause confusion...
0100 0001(0x41) | Reserved | Address of I/O Expander. Would cause confusion...
0110 1001(0x69) | Reserved | Address of Bluetooth Module. Would distract the boys...

5.3.3 Conguration

5.4 Language Codes | 6 DEBUGGING TIPS
Data type | Variable | Description
uint8_t | ammount_keys | Key count registered to the expansion device. If this is not used send 0000 0000(0x00)
uint8_t | language_set | Keyboard language set on host. Can be used to set the ASCII to keycode Table in expansion Modules with key-code sending functions. If this is not used send 0000 0000(0x00)

### 5.4 Language Codes

Language Code | Value | Comment
GERMAN | 0000 0000(0x00) | DEFAULT
ENGLISH_US | 0000 0001(0x01)

## 6 Debugging tips

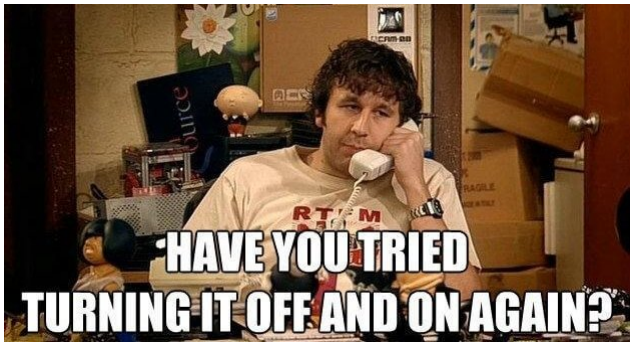
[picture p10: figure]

Figure 10: Debugging tips from the IT crowd

Sometimes the Macruwu gets stuck and cant get out (of an infinite loop or something). Unplugging it and plugging it back in again can help with that and works in 90% of all cases.
If this does not help, try the tips below.

### 6.1 Compiling rmware

- Check whether you have the correct version of the Arduino Pico framework installed. I used the newest at the time, which was version 2.6.4.
- Also check, that you have the correct libraries installed.

Adafruit NeoPixel by Adafruit (1.10.6)

Adafruit SPIFlash by Adafruit (4.0.0)

6.2 Microcontroller crashing | 6 DEBUGGING TIPS

SdFat - Adafruit Fork by Bill Greiman (2.2.1)

- If you are using Platform I/O or similar, you may have to include files other than the main separately in the compiler config

### 6.2 Microcontroller crashing

- Try running the flash_test()function in the setup. This will create themacroLayout.txt which if missing might cause the microcontroller to crash.
- If the microcontroller doesn’t get recognised by the computer, try holding down the BOOT-button on the microcontroller and while pressing it, plug the microcontroller back in to the computer. It will them show up as a new device, and COM port and you should be able to upload to it.

### 6.3 Filesystem corrupted

This can happen, if the File read protocol crashed, due to a illegal character in the macro-Layout.txt file on the flash. If this happens, please open a issue with the character, that caused the crash.
There is a way to ’restore’ it though.
1. Unplug the Macruwu and uncomment the flash_clear() command. This will clear the flash partition.
2. Hold the BOOT button (the on on the right) on the RP2040 and plug it in while pressing the button. This will manually set the microcontroller in to programming mode.
3. Select the newly appeared COM port and press upload. You may have to restart the Arduino IDE several times throughout this process, if it is stuck in a infinite upload loop. Don´t worry, this will not break anything.
4. Once uploaded, a new drive should show up. If you are under Windows you will be prompted to format the disc.
5. Once formatted, you can upload a backup of the macroLayout.txt or create a new one. DO NOT UNPLUG THE MACRUWU!
6. Go to the Arduino IDE and comment or delete the flash_clear() command.
7. Select the correct COM port and press upload. If the Arduino IDE is stuck in a infinite upload loop, restart the IDE.
8. It should be working normally again.

### 6.4 NeoPixels not working

- Check the solder connections. If the NeoPixels are not properly soldered on to the pads they will not work. Even one improperly soldered NeoPixel may cause the others to act funny. I recommend checking each connection with a multimeter, by connecting one probe to GND or 5V respectively and going through the respective pins on the NeoPixels with the other.

6.5 I/O expanders not working | 6 DEBUGGING TIPS
- If 5V and GND are connected correctly, but you are still having trouble, check the connection between the Neopixels. Dout of one and Din of the next in the chain should always be connected.

### 6.5 I/O expanders not working

- Check the solder connections
- Make sure your I/O Expanders have internal pull-up resistors. If they do not, they will not work with the Macruwu board. If you have your own board, you can also add them on the PCB, however, I did not do that with mine.
- Make sure you have set the correct address. The Base address can be found in the datasheet of the I/O expander and the variable address pars can be found in the Macruwu schematic. If you are using the same I/O listed in the materials section, the preset address should be correct.
- If you are using different I/O expanders from the ones listed in the materials section, make sure the I²C addressing scheme is correct. Other I/O expanders may need to be configured differently from the ones I used. If it turns out that you do need a setup sequence for your I/O expanders, you can create a init() method in the Expander class and call it in the setup().

### 6.6 some buttons are not being recognised

- Check the solder connections on the hot-swap sockets. They tend to form cold solder joints, that you may not always see. Especially the GND pad tends to do this. Check the connection with a multimeter by holding one probe to a known GND and going through the other connections with the other probe. The same can be done for the other side of the socket. Hold one probe on the socket and the other on the corresponding I/O expander pin.
- Make sure the key switch is installed correctly. The pins do tend to bend when pressing them in. you can check from the underside of the board, if the pin is seated in the hot-swap socket. If not, pull it out, straighten out the pin with a pair of pliers and press it back in.

If none of the above helped, fell free to contact me.
Discord: Bramble#2342

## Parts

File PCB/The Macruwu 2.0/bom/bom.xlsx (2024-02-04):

Part | Suplier Link | part nr. | price/pcs. | ammount | sum
MX Hotswap sockets | link(AliExpress) (https://de.aliexpress.com/item/1005003389366073.html) | N/A | 0.08 € | 32 | 2.62 €
SeeeduinoXIAO RP2040 | link(Mouser) (https://www.mouser.de/ProductDetail/Seeed-Studio/102010428?qs=Znm5pLBrcAJ75FCbdxzDHQ%3D%3D) | 102010428 | 5.97 € | 1 | 5.97 €
Generic 10kΩ | link(Mouser) (https://www.mouser.de/ProductDetail/652-CRT0603FZ1002ELF) | CRT0603-FZ-1002ELF | 0.04 € | 5 | 0.18 €
Generic 2.2kΩ | link(Mouser) (https://www.mouser.de/ProductDetail/791-RMC1-16K2201FTP) | RMC1/16K2201FTP | 0.01 € | 6 | 0.07 €
Generic 330Ω | link(Mouser) (https://www.mouser.de/ProductDetail/652-CR0603FX-3300ELF) | CR0603-FX-3300ELF | 0.01 € | 1 | 0.01 €
Generic 100nF | link(Mouser) (https://www.mouser.de/ProductDetail/603-CC603KRX5R9BB104) | CC0603KRX5R9BB104 | 0.02 € | 36 | 0.58 €
I/O Expander | link(Mouser) (https://www.mouser.de/ProductDetail/Diodes-Incorporated/PI4IOE5V6416LEX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) | PI4IOE5V6416LEX | 1.29 € | 2 | 2.58 €
Power Diode | link(Mouser) (https://www.mouser.de/ProductDetail/Bourns/CD123D-B140LR?qs=xhbEVWpZdWeACvF%2F8gDRTg%3D%3D) | CD123D-B140LR | 0.34 € | 1 | 0.34 €
Level shifter | link(Mouser) (https://www.mouser.de/ProductDetail/Texas-Instruments/LSF0204QPWRQ1?qs=w%2Fv1CP2dgqqt88p%2F1xId1A%3D%3D) | LSF0204QPWRQ1 | 1.08 € | 1 | 1.08 €
Adressable RGBLEDs | link(Mouser) (https://de.aliexpress.com/item/1005003636607308.html) | SK6803 MINI-E 3MA | 0.09 € | 32 | 3.01 €
PCB | N/A | N/A | 6.23 € | 1 | 6.23 €
Switch (Gateron yellow) | link(AliExpress) (https://www.aliexpress.com/p/order/index.html?spm=a2g0o.home.headerAcount.2.22e712e2rwSaA6) | N/A | 0.28 € | 32 | 9.11 €
Base (3D Printed) | N/A | N/A | 2.50 € | 1 | 2.50 €
Plate (3D Printed) | N/A | N/A | 1.00 € | 1 | 1.00 €
Relegendable Keycaps | link(AliExpress) (https://de.aliexpress.com/item/1005003047698548.html) | N/A | 0.19 € | 32 | 6.05 €
 |  |  |  |  | 41.32 €

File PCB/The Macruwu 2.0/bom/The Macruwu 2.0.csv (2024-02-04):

Id | Designator | Footprint | Quantity | Designation | Supplier and ref
1 | U3,U15,U14,U8,U5,U22,U16,U18,U28,U17,U20,U32,U2,U9,U10,U29,U25,U23,U31,U6,U12,U4,U7,U19,U30,U1,U11,U26,U24,U21,U27,U13 | Multi Hotswap with RGB | 32 | Multi_Hotswap_with_RGB
2 | U33 | Seeeduino XIAO-MOUDLE14P-2.54-21X17.8MM-MINIMAL-PADS | 1 | SeeeduinoXIAO
3 | R3,R4,R1,R2,R11 | R_0603_1608Metric_Pad0.98x0.95mm_HandSolder | 5 | 10k
4 | S1,S2 | SJ235954BSMTTR | 2 | SJ2-35954B-SMT-TR
5 | J2 | PinHeader_1x04_P2.54mm_Vertical | 1 | I²C 5V 2
6 | J3 | PinHeader_1x04_P2.54mm_Vertical | 1 | I²C 5V 3
7 | J1 | PinHeader_1x04_P2.54mm_Vertical | 1 | I²C 5V 1
8 | C9,C7,C2,C20,C24,C18,C1,C19,C22,C11,C25,C28,C5,C35,C14,C34,C32,C13,C17,C16,C21,C27,C33,C29,C31,C3,C30,C26,C6,C12,C10,C8,C23,C4,C15,C36 | C_0603_1608Metric_Pad1.08x0.95mm_HandSolder | 36 | 100n
9 | R5,R10,R6,R9,R8,R7 | R_0603_1608Metric_Pad0.98x0.95mm_HandSolder | 6 | 2k2
10 | IC2,IC1 | SOP65P640X120-24N | 2 | PI4IOE5V6416LEX
11 | D1 | CD123DB140LR | 1 | CD123D-B140LR
12 | R12 | R_0603_1608Metric_Pad0.98x0.95mm_HandSolder | 1 | 330
13 | IC3 | SOP65P640X120-14N | 1 | LSF0204QPWRQ1
14 | J4 | PinHeader_1x05_P2.54mm_Vertical | 1 | Battery Bluetooth Expansion

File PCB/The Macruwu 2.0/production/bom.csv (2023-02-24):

Designator | Footprint | Quantity | Value | LCSC Part #
C1 | 0603 | 1 | 100n
C10 | 0603 | 1 | 100n
C11 | 0603 | 1 | 100n
C12 | 0603 | 1 | 100n
C13 | 0603 | 1 | 100n
C14 | 0603 | 1 | 100n
C15 | 0603 | 1 | 100n
C16 | 0603 | 1 | 100n
C17 | 0603 | 1 | 100n
C18 | 0603 | 1 | 100n
C19 | 0603 | 1 | 100n
C2 | 0603 | 1 | 100n
C20 | 0603 | 1 | 100n
C21 | 0603 | 1 | 100n
C22 | 0603 | 1 | 100n
C23 | 0603 | 1 | 100n
C24 | 0603 | 1 | 100n
C25 | 0603 | 1 | 100n
C26 | 0603 | 1 | 100n
C27 | 0603 | 1 | 100n
C28 | 0603 | 1 | 100n
C29 | 0603 | 1 | 100n
C3 | 0603 | 1 | 100n
C30 | 0603 | 1 | 100n
C31 | 0603 | 1 | 100n
C32 | 0603 | 1 | 100n
C33 | 0603 | 1 | 100n
C34 | 0603 | 1 | 100n
C35 | 0603 | 1 | 100n
C36 | 0603 | 1 | 100n
C4 | 0603 | 1 | 100n
C5 | 0603 | 1 | 100n
C6 | 0603 | 1 | 100n
C7 | 0603 | 1 | 100n
C8 | 0603 | 1 | 100n
C9 | 0603 | 1 | 100n
D1 | CD123DB140LR | 1 | CD123D-B140LR
IC1, IC2 | SOP65P640X120-24N | 2 | PI4IOE5V6416LEX
IC3 | SOP65P640X120-14N | 1 | LSF0204QPWRQ1
J1 | PinHeader_1x04_P2.54mm_Vertical | 1 | I²C 5V 1
J2 | PinHeader_1x04_P2.54mm_Vertical | 1 | I²C 5V 2
J3 | PinHeader_1x04_P2.54mm_Vertical | 1 | I²C 5V 3
J4 | PinHeader_1x05_P2.54mm_Vertical | 1 | Battery Bluetooth Expansion
R1 | 0603 | 1 | 10k
R10 | 0603 | 1 | 2k2
R11 | 0603 | 1 | 10k
R12 | 0603 | 1 | 330
R2 | 0603 | 1 | 10k
R3 | 0603 | 1 | 10k
R4 | 0603 | 1 | 10k
R5 | 0603 | 1 | 2k2
R6 | 0603 | 1 | 2k2
R7 | 0603 | 1 | 2k2
R8 | 0603 | 1 | 2k2
R9 | 0603 | 1 | 2k2
S1, S2 | SJ235954BSMTTR | 2 | SJ2-35954B-SMT-TR
U1, U10, U11, U12, U13, U14, U15, U16, U17, U18, U19, U2, U20, U21, U22, U23, U24, U25, U26, U27, U28, U29, U3, U30, U31, U32, U4, U5, U6, U7, U8, U9 | Multi Hotswap with RGB | 32 | Multi_Hotswap_with_RGB
U33 | Seeeduino XIAO-MOUDLE14P-2.54-21X17.8MM-MINIMAL-PADS | 1 | SeeeduinoXIAO

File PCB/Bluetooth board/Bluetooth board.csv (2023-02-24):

Source: | D:\#Elektronics\The Macruwu\#The macruwu 2.0\Bluetooth board\Bluetooth board.kicad_sch
Date: | 27/01/2023 14:55:29
Tool: | Eeschema (6.0.10)
Generator: | C:\Program Files\KiCad\6.0\bin\scripting\plugins/bom_csv_grouped_by_value_with_fp.py
Component Count: | 43
Ref | Qnty | Value | Cmp name | Footprint | Description | Vendor
BT1, | 1 | BH-18650-PC | BH-18650-PC | SamacSys_Parts:BH18650PC | BATTERY HOLDER 18650 PC PIN
C1, C6, | 2 | 10uF | C | Capacitor_SMD:C_0603_1608Metric_Pad1.08x0.95mm_HandSolder | Unpolarized capacitor
C2, C5, | 2 | 100n | C | Capacitor_SMD:C_0603_1608Metric_Pad1.08x0.95mm_HandSolder | Unpolarized capacitor
C3, C4, C7, C8, | 4 | 22uF | C | Capacitor_SMD:C_1206_3216Metric_Pad1.33x1.80mm_HandSolder | Unpolarized capacitor
D1, | 1 | GREEN | LED | LED_THT:LED_D5.0mm | Light emitting diode
D2, | 1 | RED | LED | LED_THT:LED_D5.0mm | Light emitting diode
D3, D5, | 2 | CD123D-B140LR | CD123D-B140LR | SamacSys_Parts:CD123DB140LR | BOURNS - CD123D-B140LR - Small Signal Schottky Diode, Single, 40 V, 1 A, 380 mV, 20 A, 125 C
D4, | 1 | SS34 | SS34 | SamacSys_Parts:DIOM7959X262N | TAIWAN SEMICONDUCTOR - SS34 - DIODE, SCHOTTKY, 3A, 40V
IC1, | 1 | FS312F-G | FS312F-G | SamacSys_Parts:SOT95P280X145-6N | One Cell Lithium-ion/Polymer Battery Protection IC
IC2, | 1 | IRLML6401 | IRLML6401 | SamacSys_Parts:SOT95P237X112-3N | MOSFET P Channel 12V 4.3A 950mV @ 250uA 50m @ 4.3A,4.5V SOT-23 RoHS
IC3, | 1 | LM321MF | LM321MF | SamacSys_Parts:SOT95P280X145-5N | Low Power Single Op Amp
IC4, | 1 | MT3608 | MT3608 | SamacSys_Parts:SOT95P280X145-6N | High Efficiency 1.2MHz 2A Step Up Converter
J1, | 1 | TP4056 | TP4056 | SamacSys_Parts:SOIC127P600X175-9N | 1A Standalone Linear Li-lon Battery Charger, SOP-8
J2, | 1 | ON/OFF switch | Conn_01x02 | Connector_PinHeader_2.54mm:PinHeader_1x02_P2.54mm_Vertical | Generic connector, single row, 01x02, script generated (kicad-library-utils/schlib/autogen/connector/)
J3, | 1 | Battery Bluetooth Expansion | Conn_01x05 | Connector_PinSocket_2.54mm:PinSocket_1x05_P2.54mm_Vertical | Generic connector, single row, 01x05, script generated (kicad-library-utils/schlib/autogen/connector/)
J4, | 1 | Battery IN | Conn_01x02 | Connector_PinHeader_2.54mm:PinHeader_1x02_P2.54mm_Vertical | Generic connector, single row, 01x02, script generated (kicad-library-utils/schlib/autogen/connector/)
J5, | 1 | Conn_02x04_Odd_Even | Conn_02x04_Odd_Even | Connector_PinHeader_2.54mm:PinHeader_2x04_P2.54mm_Vertical | Generic connector, double row, 02x04, odd/even pin numbering scheme (row 1 odd numbers, row 2 even numbers), script generated (kicad-library-utils/schlib/autogen/connector/)
L1, | 1 | 22uH | L | Inductor_SMD:L_12x12mm_H6mm | Inductor
Q1, | 1 | FS8205A | FS8205A | SamacSys_Parts:SOP65P640X120-8N | Dual N-Channel Enahncement Mode Power MOSFET
R1, | 1 | 2k | R | Resistor_SMD:R_0603_1608Metric_Pad0.98x0.95mm_HandSolder | Resistor
R2, | 1 | 100 | R | Resistor_SMD:R_0603_1608Metric_Pad0.98x0.95mm_HandSolder | Resistor
R3, R4, R5, R11, R15, | 5 | 1k | R | Resistor_SMD:R_0603_1608Metric_Pad0.98x0.95mm_HandSolder | Resistor
R6, R10, | 2 | 4.99M | R | Resistor_SMD:R_0603_1608Metric_Pad0.98x0.95mm_HandSolder | Resistor
R7, | 1 | 7.5k | R | Resistor_SMD:R_0603_1608Metric_Pad0.98x0.95mm_HandSolder | Resistor
R8, R13, R14, | 3 | 100k | R | Resistor_SMD:R_0603_1608Metric_Pad0.98x0.95mm_HandSolder | Resistor
R9, | 1 | 10M | R | Resistor_SMD:R_0603_1608Metric_Pad0.98x0.95mm_HandSolder | Resistor
R12, R16, | 2 | 0 | R | Resistor_SMD:R_0603_1608Metric_Pad0.98x0.95mm_HandSolder | Resistor
U1, | 1 | MOUDLE-SEEEDUINO-XIAO-ESP32C3 | MOUDLE-SEEEDUINO-XIAO-ESP32C3 | xiao ESP32C3_PCB:MOUDLE14P-SMD-2.54-21X17.8MM
U2, | 1 | AMS1117-3.3 | AMS1117-3.3 | Package_TO_SOT_SMD:SOT-223-3_TabPin2 | 1A Low Dropout regulator, positive, 3.3V fixed output, SOT-223

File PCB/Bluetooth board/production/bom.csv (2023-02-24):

Designator | Footprint | Quantity | Value | LCSC Part #
C1 | 0603 | 1 | 10uF | C96446
C2 | 0603 | 1 | 100n | C14663
C3 | 1206 | 1 | 22uF | C12891
C4 | 1206 | 1 | 22uF | C12891
C5 | 0603 | 1 | 100n | C14663
C6 | 0603 | 1 | 10uF | C96446
C7 | 1206 | 1 | 22uF | C12891
C8 | 1206 | 1 | 22uF | C12891
D4 | D_SMA | 1 | SS34 | C8678
IC1 | SOT95P280X145-6N | 1 | FS312F-G | C82736
IC2 | SOT95P237X112-3N | 1 | AO3401A | C15127
IC3 | SOT95P280X145-5N | 1 | LM321MF | C668208
IC4 | SOT95P280X145-6N | 1 | MT3608 | C84817
J1 | SOIC127P600X175-9N | 1 | TP4056 | C16581
L1 | L_12x12mm_H6mm | 1 | 22uH | C2929501
Q1 | SOP65P640X120-8N | 1 | FS8205A | C16052
R1 | 0603 | 1 | 2k | C22975
R10 | 0603 | 1 | 4.99M | C158914
R11 | 0603 | 1 | 1k | C21190
R13 | 0603 | 1 | 7.5k | C5140717
R14 | 0603 | 1 | 10k | C25804
R15 | 0603 | 1 | 1k | C21190
R2 | 0603 | 1 | 100 | C22775
R3 | 0603 | 1 | 1k | C21190
R4 | 0603 | 1 | 1k | C21190
R5 | 0603 | 1 | 1k | C21190
R6 | 0603 | 1 | 4.99M | C158914
R7 | 0603 | 1 | 7.5k | C5140717
R8 | 0603 | 1 | 10k | C25804
R9 | 0603 | 1 | 10M | C2907090
U2 | SOT-223-3_TabPin2 | 1 | AMS1117-3.3 | C6186

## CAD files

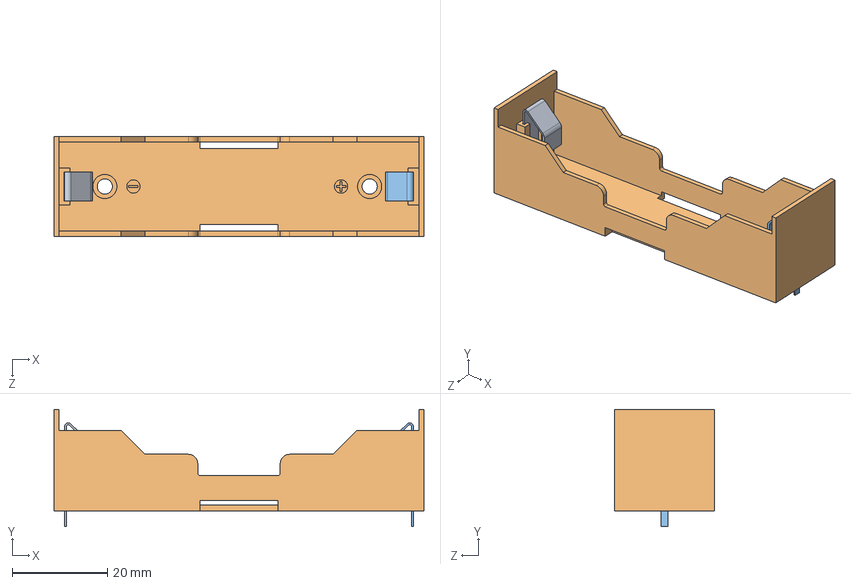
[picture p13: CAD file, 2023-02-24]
3D Moddels/Case/Bluetooth board/BH-18650-PC.SLDASM
77.7 x 24.6 x 20.9 mm
BH-18650-PC1.stp
BH-18650-PC2.stp
BH-18650-PC3.stp

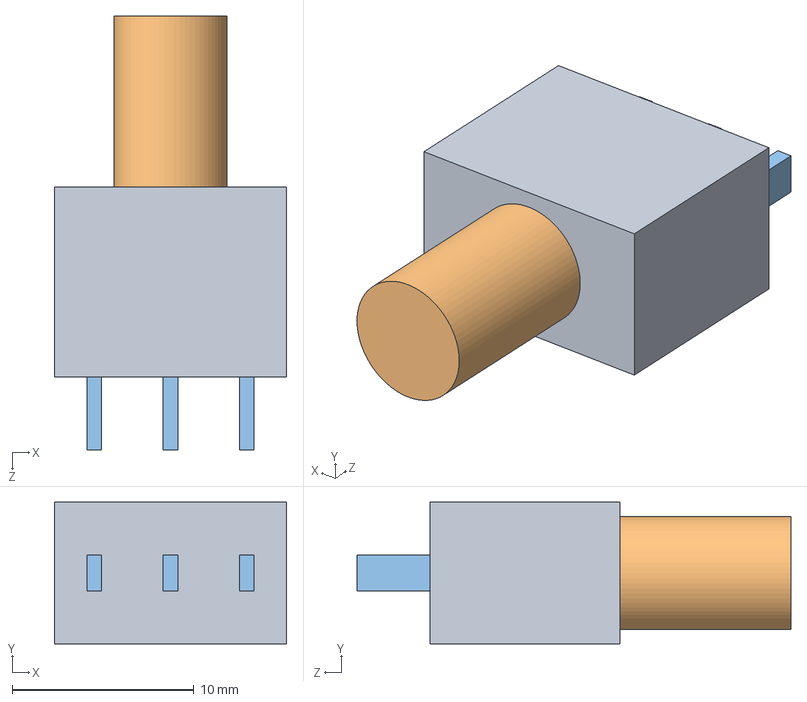
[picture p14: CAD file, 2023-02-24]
3D Moddels/Case/Switch/Switch.SLDASM
12.8 x 7.80 x 23.9 mm

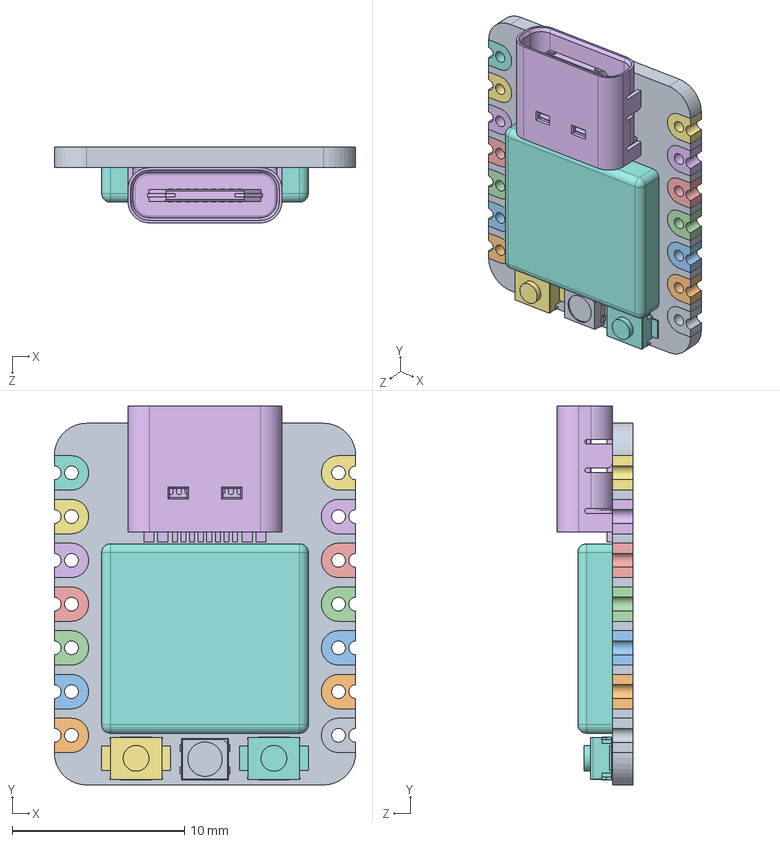
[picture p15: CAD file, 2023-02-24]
PCB/The Macruwu 2.0/Seeeduino XIAO KICAD/seeed-studio-xiao-esp32c3-3d-model/Seeed Studio XIAO ESP32.step.SLDASM
17.5 x 22.0 x 4.41 mm
Shell.step
DOUT.step
DIN.step
VSS.step
VDD.step
type-c v2.step
smd_button v3.step
smd_button v3(Mirror).step
main-0.step
main-1.step
main-2.step
main-3.step
main-4.step
main-5.step
main-6.step
main-7.step
main-8.step
main-9.step
main-10.step
main-11.step
main-12.step
main-13.step
main-14.step
main-15.step

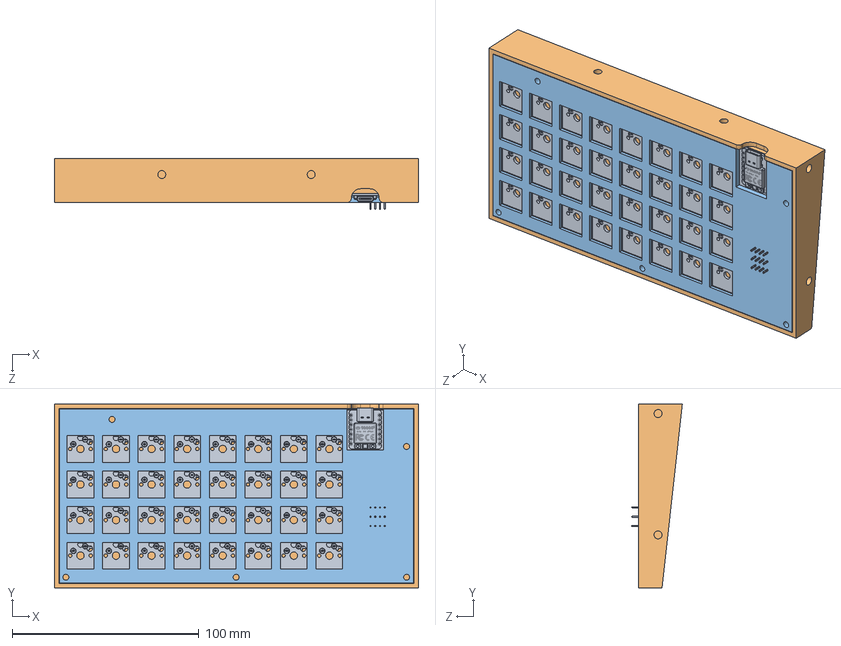
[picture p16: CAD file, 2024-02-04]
3D Moddels/Case/Base no battery/Base no battery.SLDASM
195.0 x 98.3 x 27.1 mm
The Macruwu 2.0.step
Plate V2

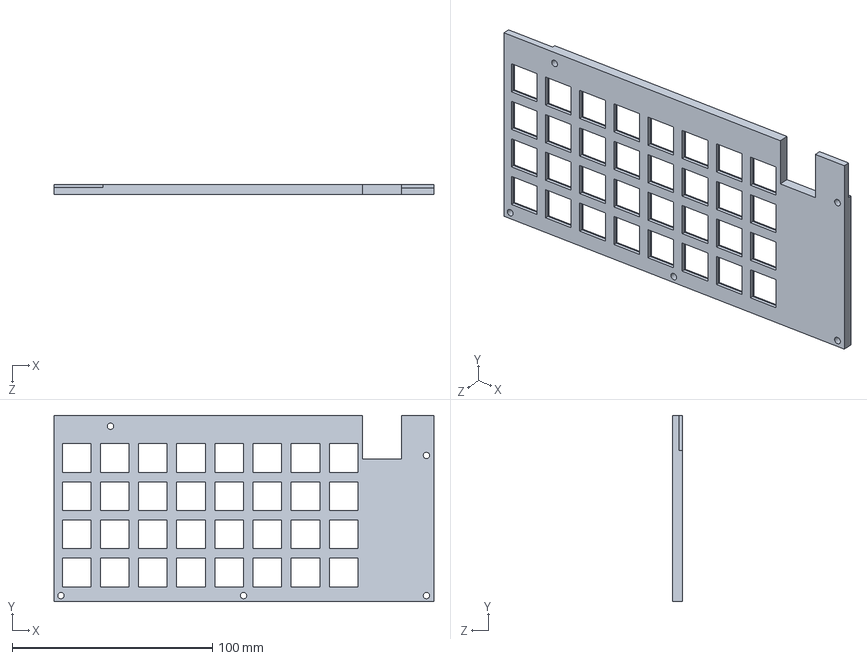
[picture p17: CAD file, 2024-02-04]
3D Moddels/Case/Base no battery/Plate V2.SLDPRT
189.8 x 93.1 x 4.80 mm

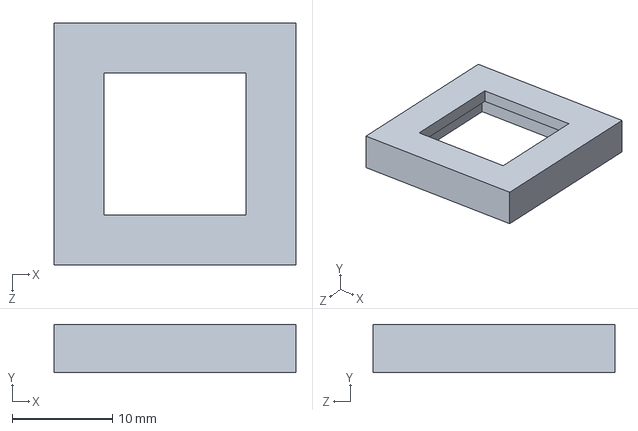
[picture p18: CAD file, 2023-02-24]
3D Moddels/Case/Base/Keyplate Holder test.step.SLDPRT
24.1 x 4.80 x 24.1 mm

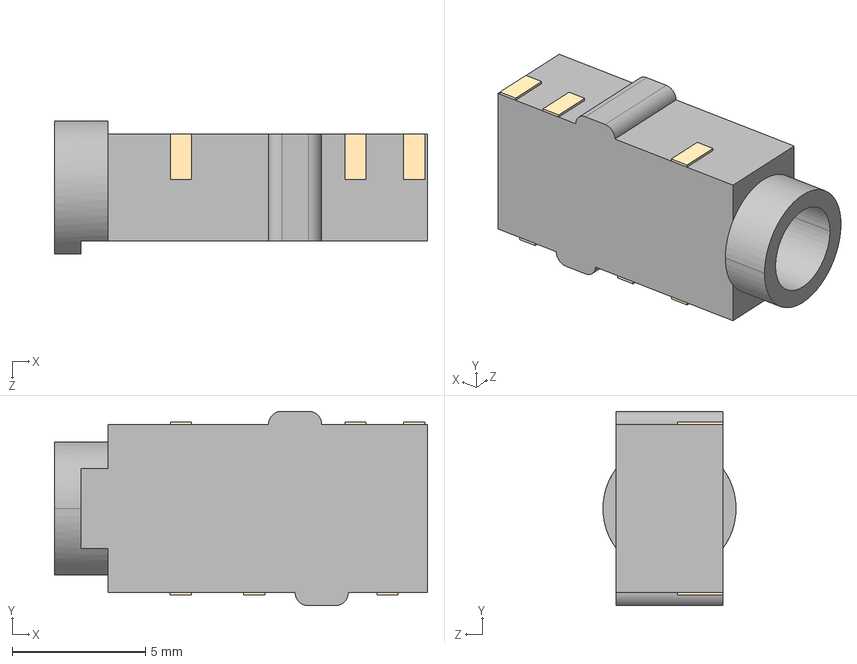
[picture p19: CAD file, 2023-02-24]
PCB/The Macruwu 2.0/Headphone Jack/Headphone Jack.STEP
14.0 x 7.30 x 5.00 mm
Part1^Headphone Jack
Part5^Headphone Jack

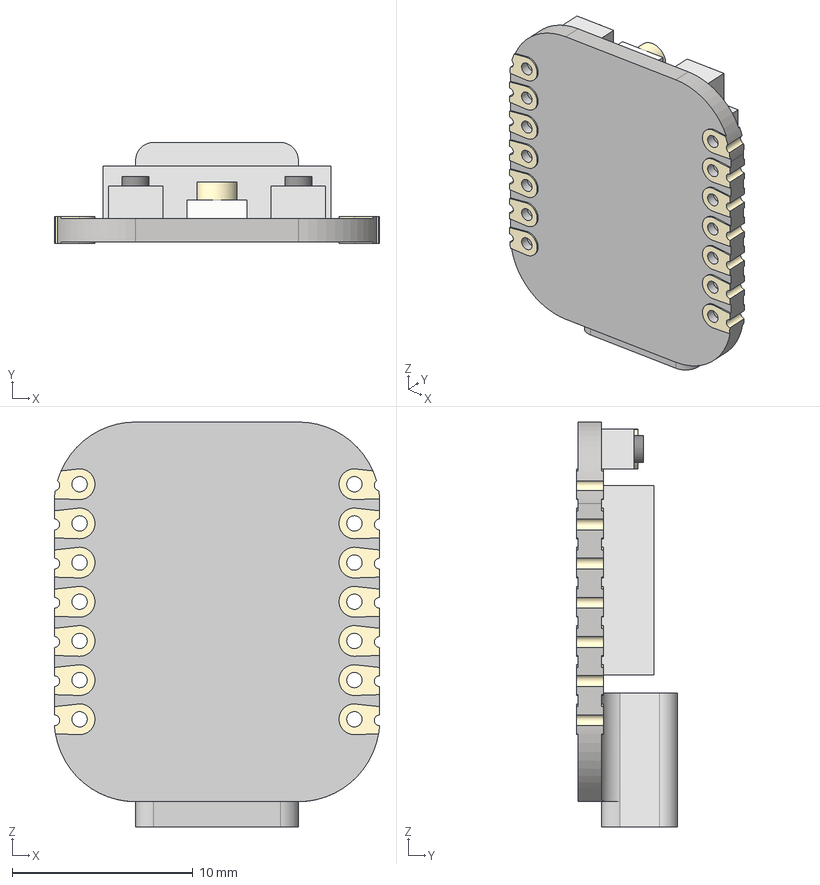
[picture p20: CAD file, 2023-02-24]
PCB/The Macruwu 2.0/Seeeduino XIAO KICAD/seeed-studio-xiao-esp32c3-3d-model/SEEED Esp32 C3 mini v2.step
18.0 x 5.60 x 22.4 mm

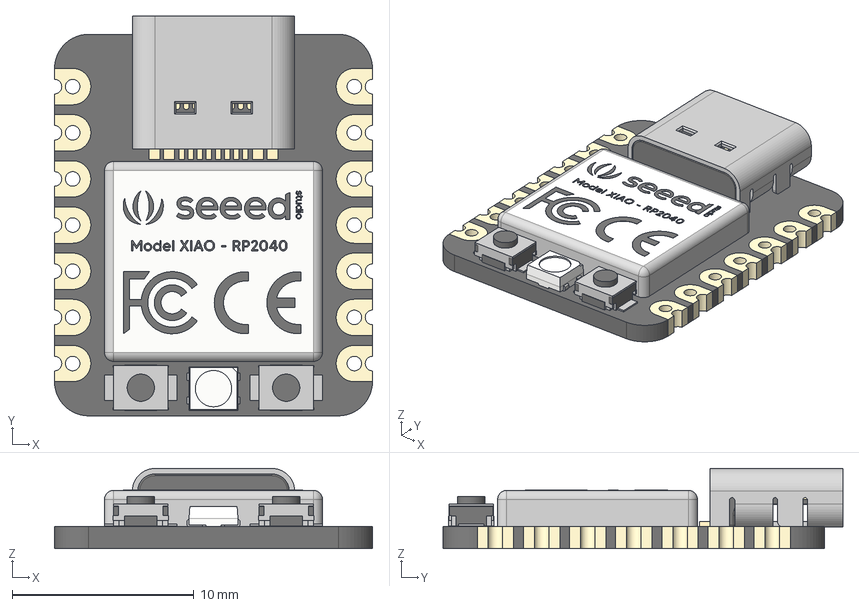
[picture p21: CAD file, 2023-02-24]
PCB/The Macruwu 2.0/Seeeduino XIAO KICAD/seeed-studio-xiao-rp2040-1.snapshot.4/Seeed Studio XIAO RP2040 v26.step
17.5 x 22.0 x 4.40 mm
type-c v2
smd_button v3
DOUT
DIN
VSS
VDD
smd_button v3(Mirror)

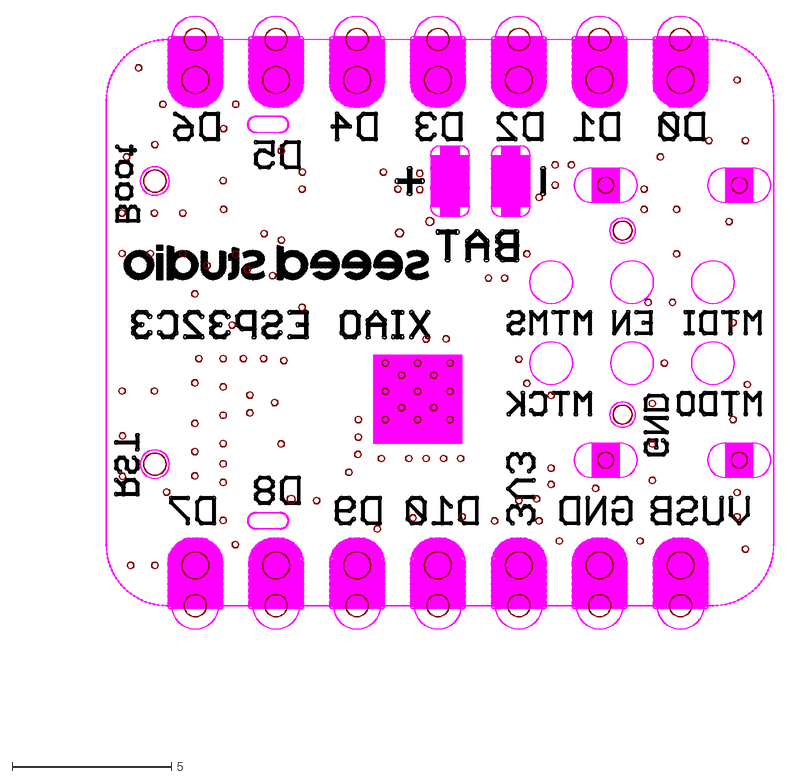
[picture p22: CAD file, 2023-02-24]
PCB/The Macruwu 2.0/Seeeduino XIAO KICAD/XIAO-ESP32C3-DXF/113991054/bottom.dxf
23.8 x 22.7

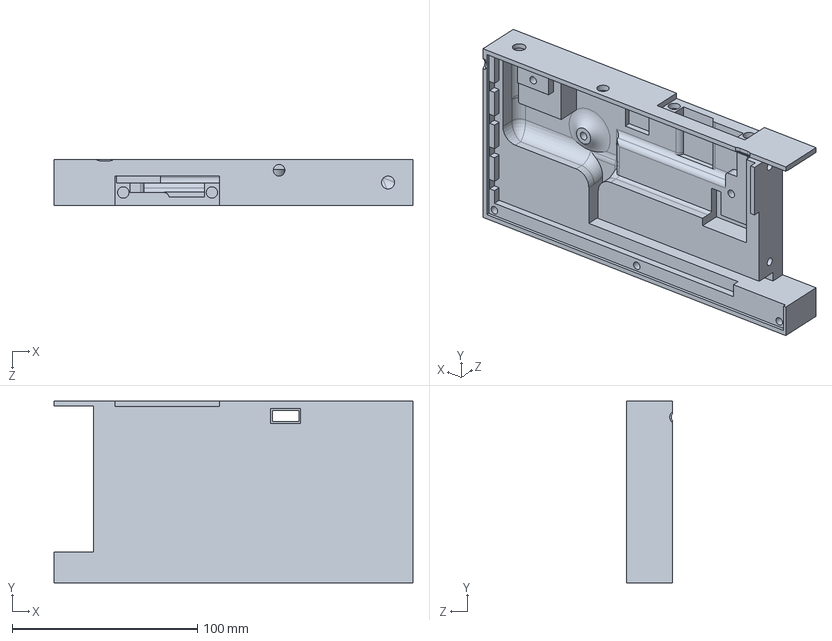
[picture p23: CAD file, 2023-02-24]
3D Moddels/Case/Base/Base.SLDPRT
194.0 x 98.3 x 24.8 mm

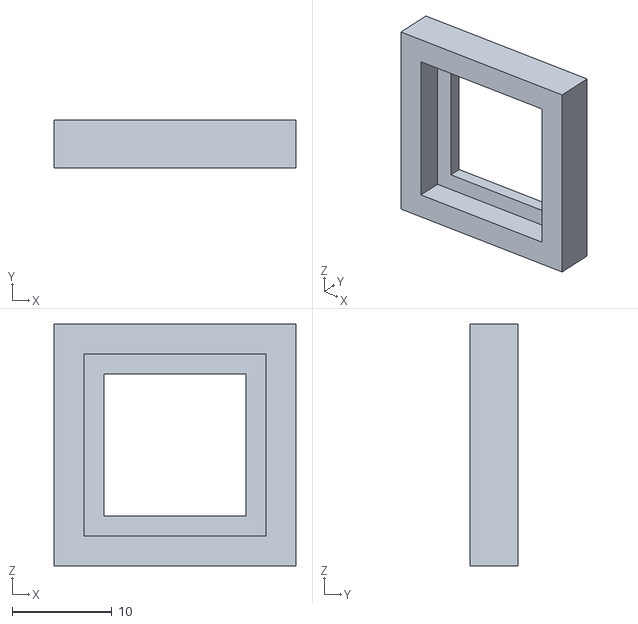
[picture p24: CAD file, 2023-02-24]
3D Moddels/Keyplate Holder testfits/Keyplate Holder test 14.2mm.STL
24.2 x 4.80 x 24.2

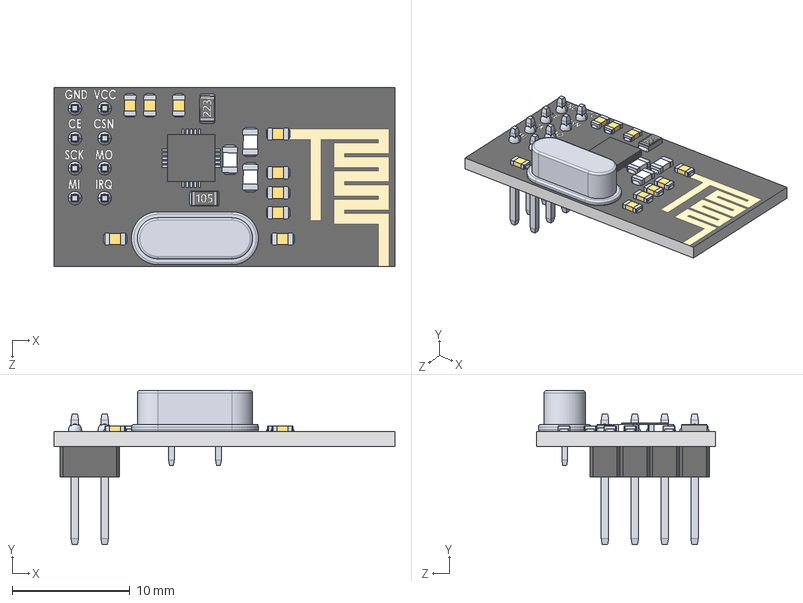
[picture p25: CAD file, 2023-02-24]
PCB/Bluetooth board/NRF24L01.step
29.0 x 13.1 x 15.2 mm
nrfboard
CrystalOscillator
doubleMaleHeader x 4
solder x 8
1.7mmSmdCeramicCapacitor x 9
smdResistor223
smdResistor105
smdceramiccapacitorwhite x 3
4x4SMDchip

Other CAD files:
PCB/Bluetooth board/CD123D-B140LR.step.SLDASM
3D Moddels/Case/Switch/Part503.SLDPRT
3D Moddels/Keyplate Holder testfits/Keyplate Holder test.STEP
3D Moddels/Case/Base no battery/Plate V2 no headphone.STL
3D Moddels/Case/Switch/Part504.SLDPRT
3D Moddels/Case/Base no battery/Part1 no headphone.STL
3D Moddels/Case/Base no battery/Part1.SLDPRT
3D Moddels/Case/Base no battery/Part1.STL
3D Moddels/Case/Base no battery/Plate V2.STL
3D Moddels/Case/Base/Base.STL
3D Moddels/Case/Base/Bluetooth cover.SLDPRT
3D Moddels/Case/Base/Bluetooth cover.STL
3D Moddels/Case/Base/LED Cover.SLDPRT
3D Moddels/Case/Base/LED Cover.STL
3D Moddels/Case/Base/Plate.SLDPRT
3D Moddels/Case/Base/Plate.STL
3D Moddels/Case/Switch/Part505.SLDPRT
3D Moddels/Keyplate Holder testfits/Keyplate Holder test 14.0mm.STL
3D Moddels/Keyplate Holder testfits/Keyplate Holder test 14.1mm.STL
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

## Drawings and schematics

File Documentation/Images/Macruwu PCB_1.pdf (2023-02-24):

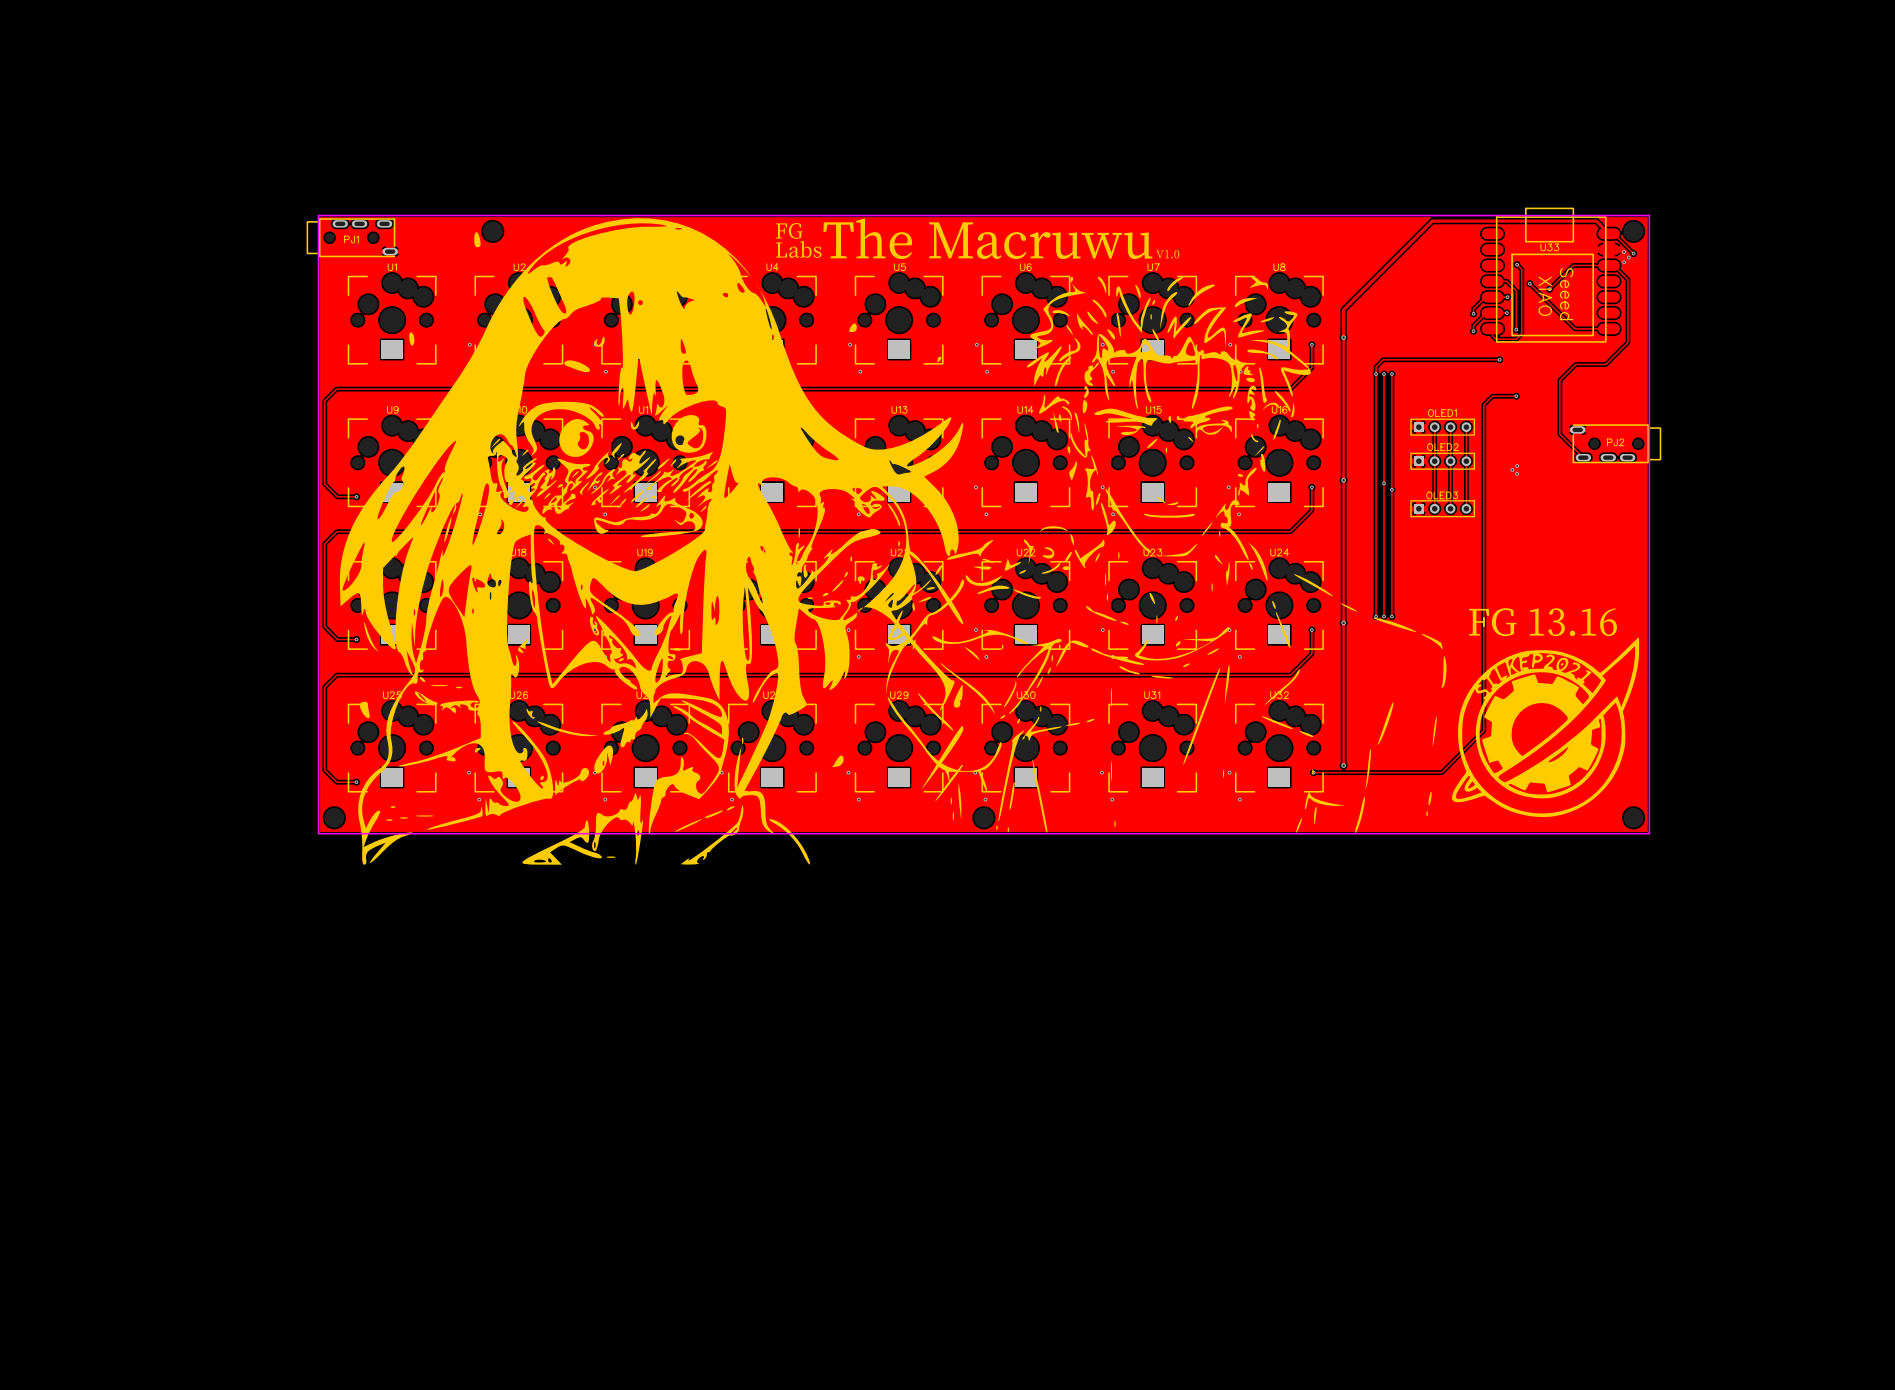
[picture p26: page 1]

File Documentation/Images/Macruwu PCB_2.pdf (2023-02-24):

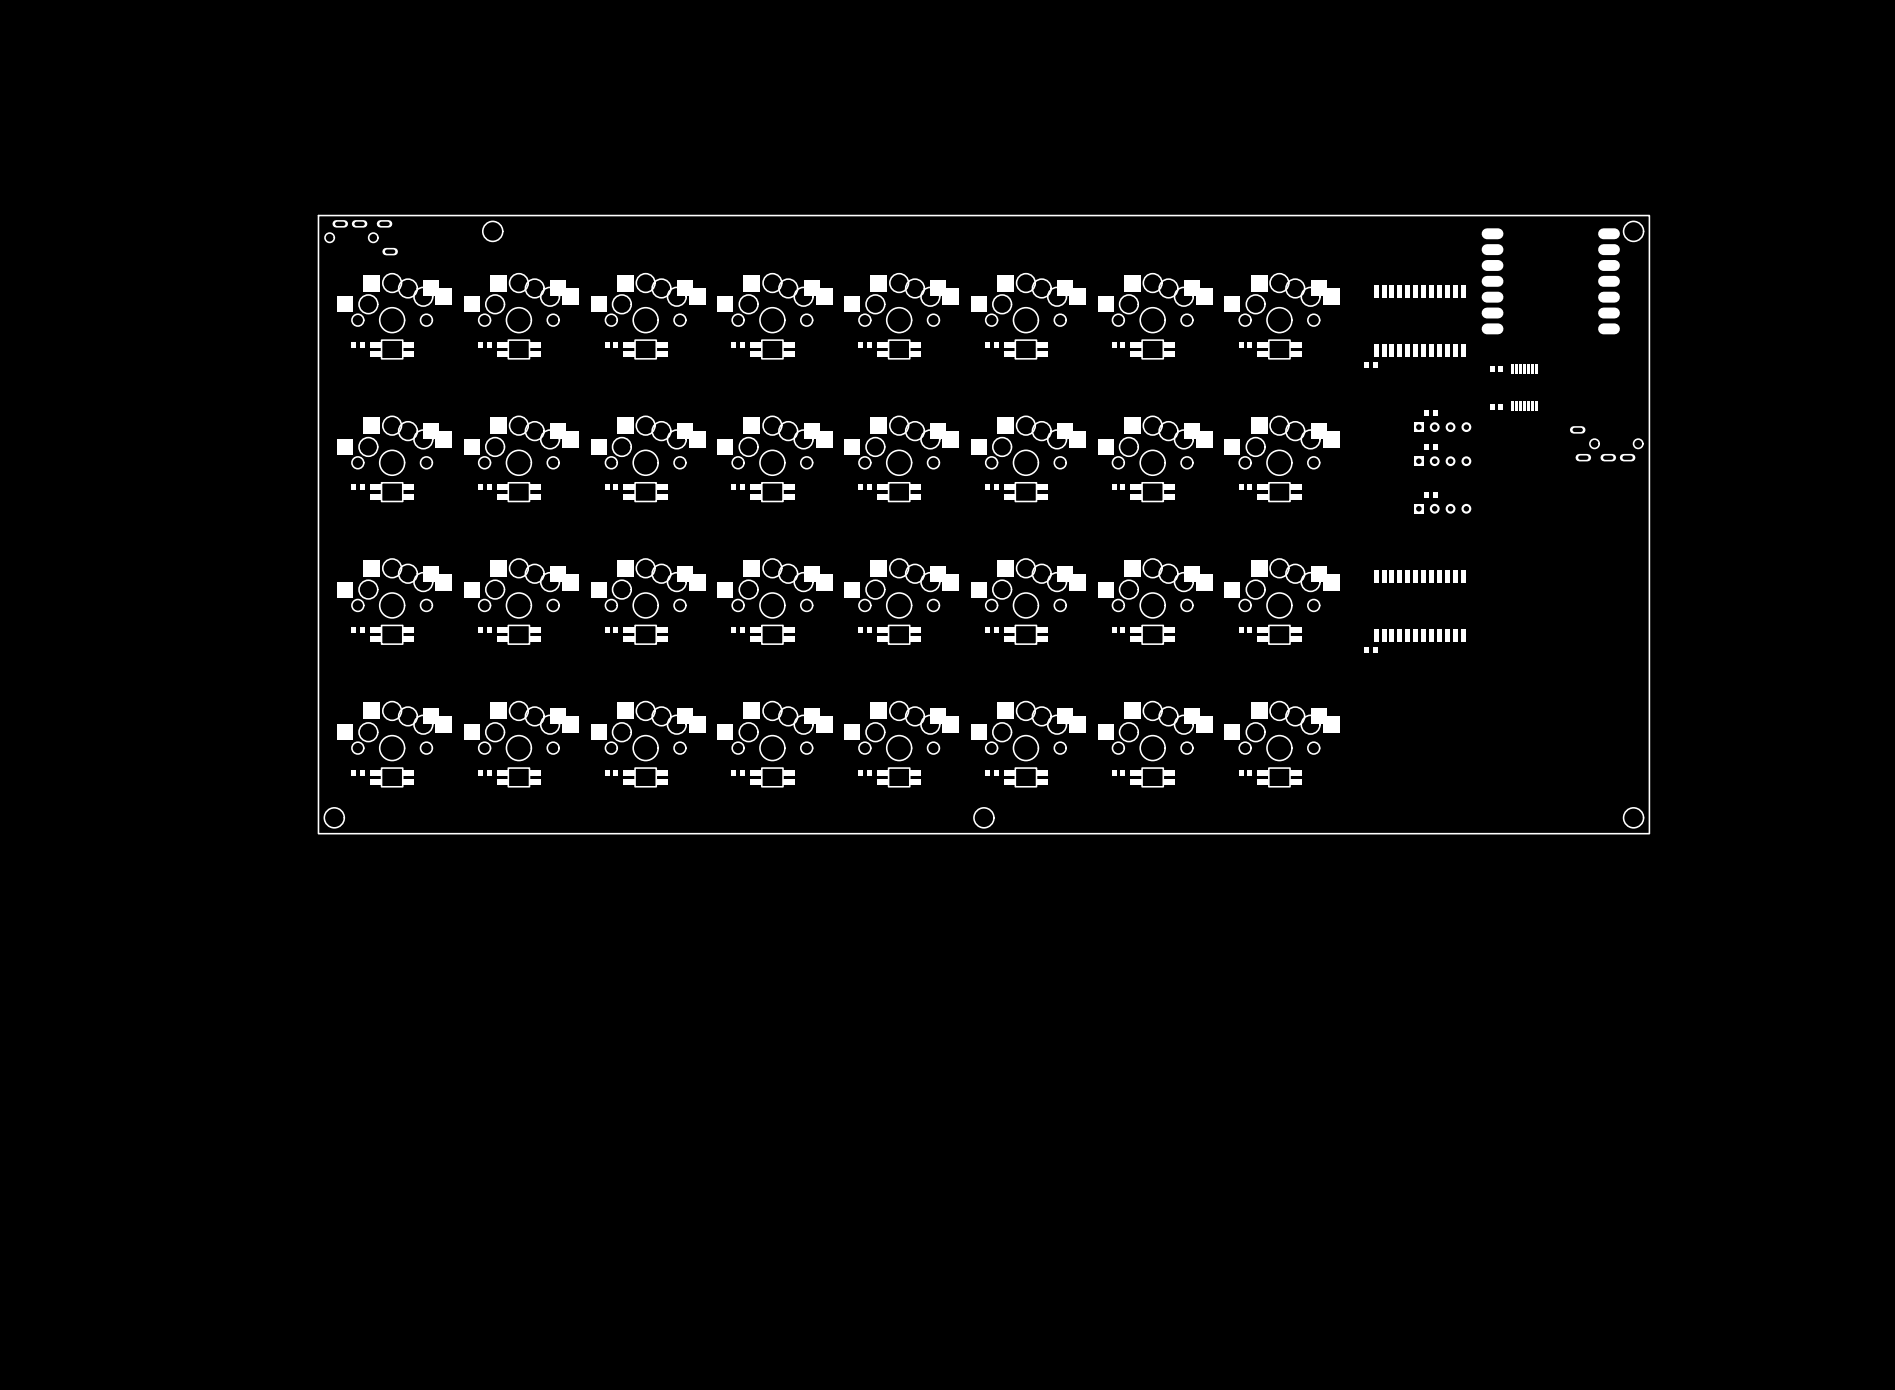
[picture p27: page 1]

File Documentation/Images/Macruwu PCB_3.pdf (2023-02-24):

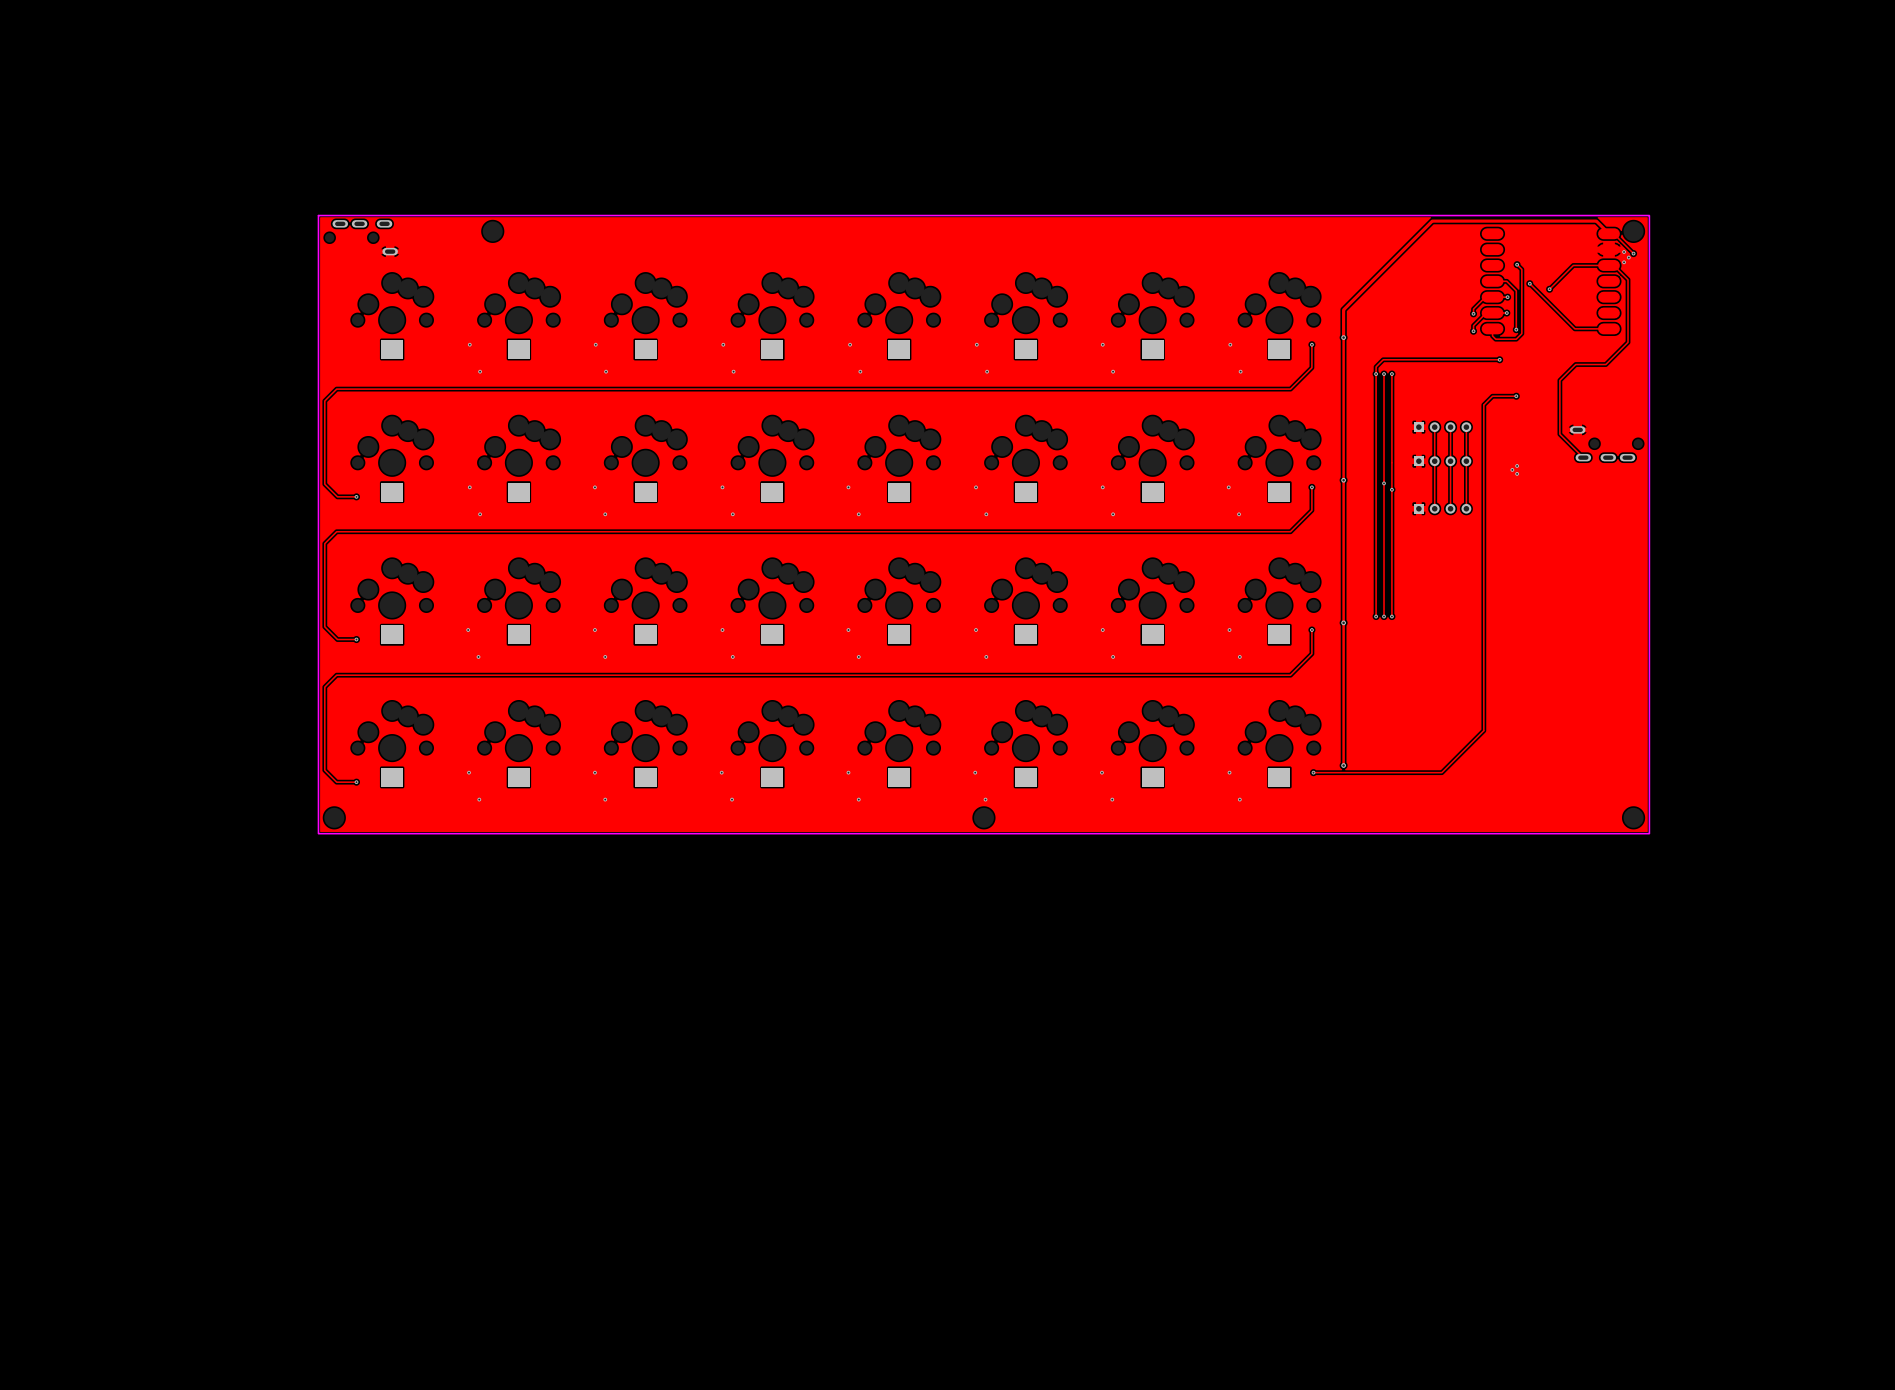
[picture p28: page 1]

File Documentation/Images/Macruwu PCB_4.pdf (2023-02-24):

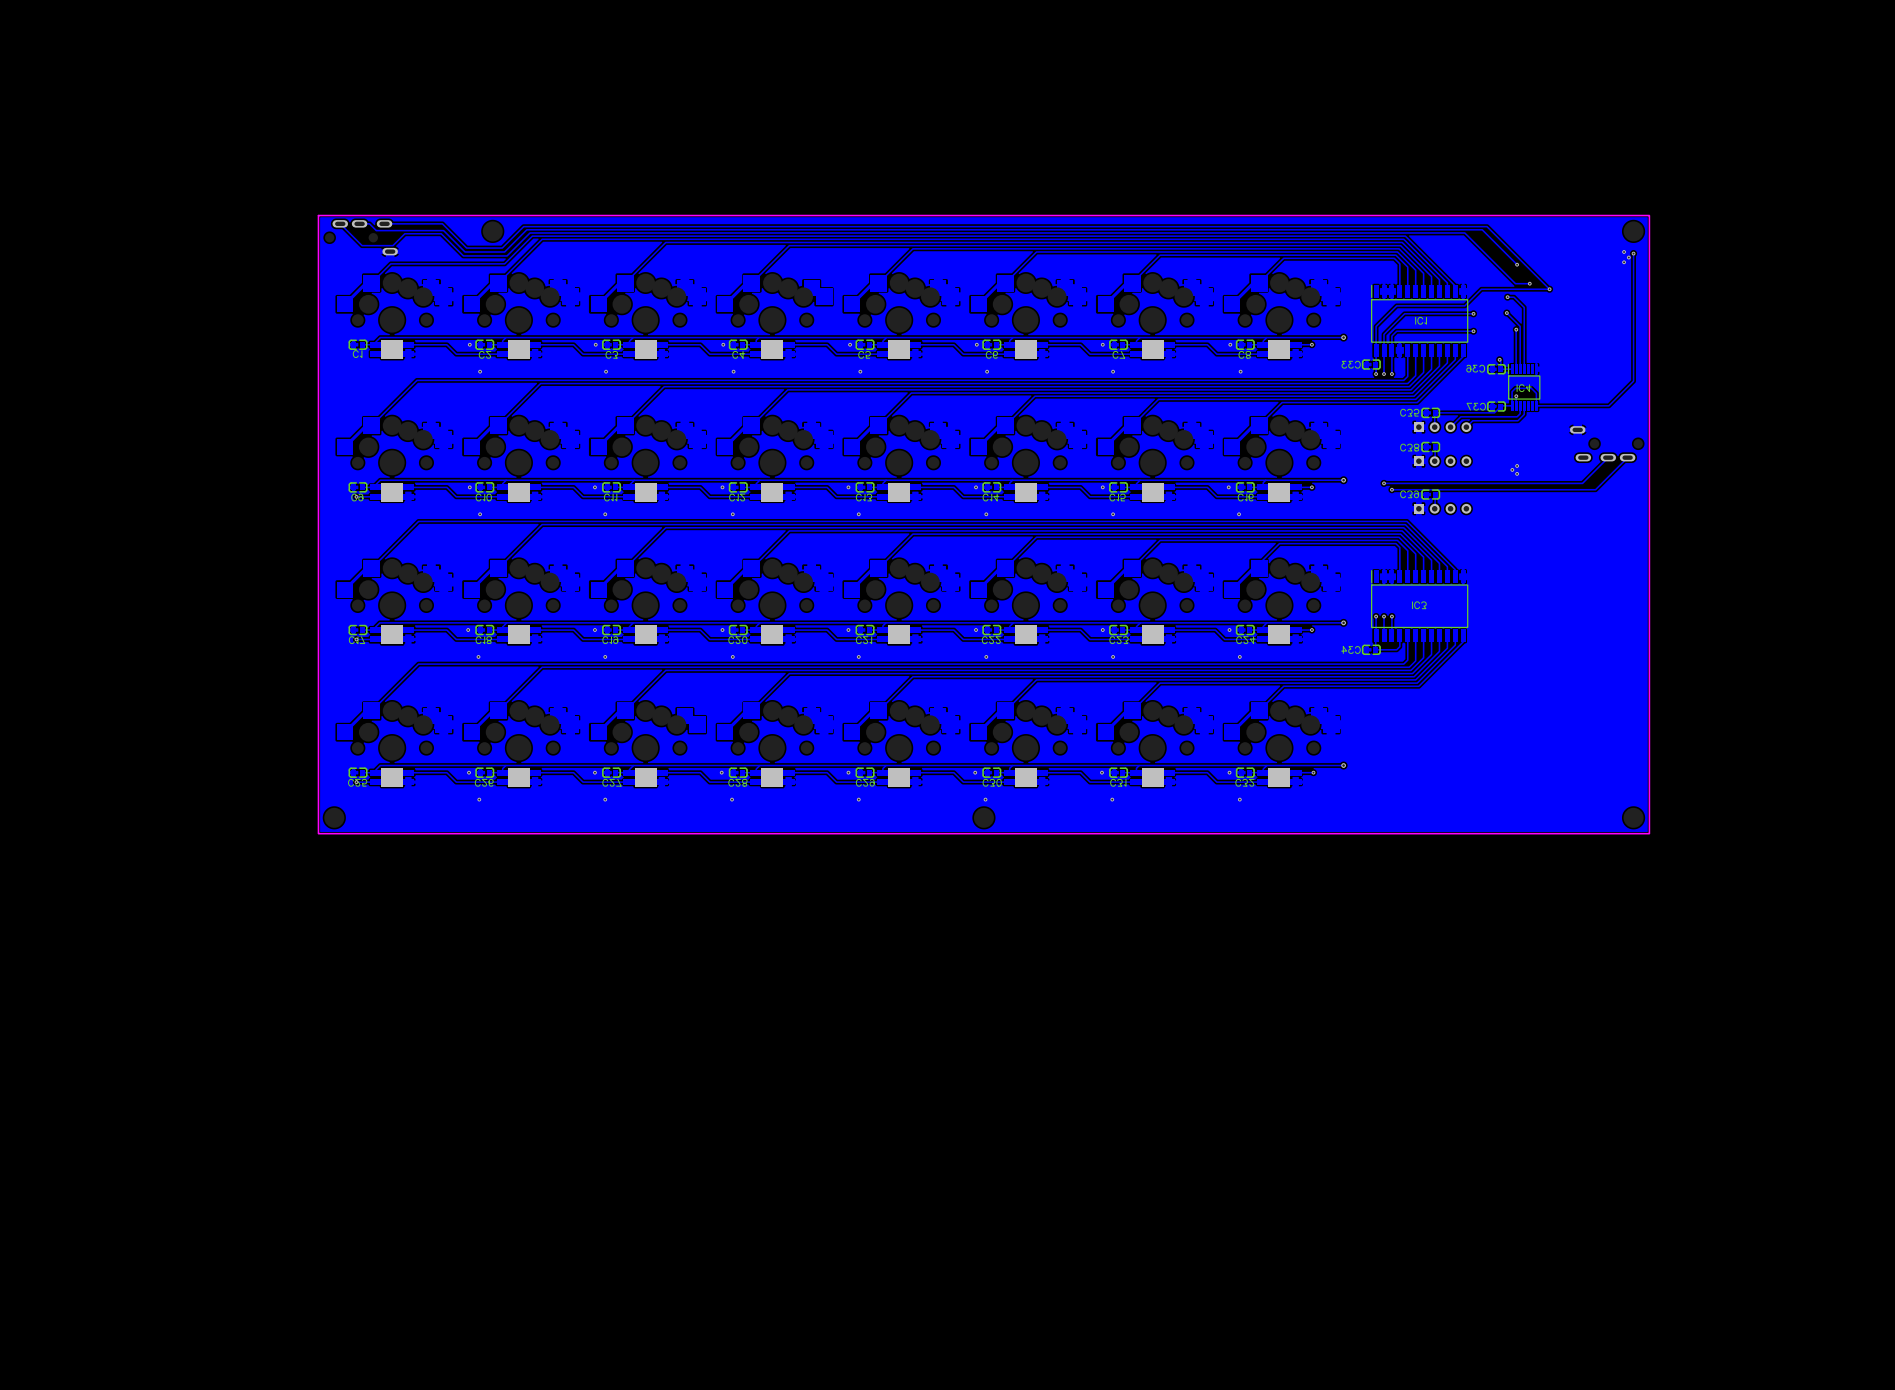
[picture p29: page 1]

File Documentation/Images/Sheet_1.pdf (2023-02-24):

A | A

1

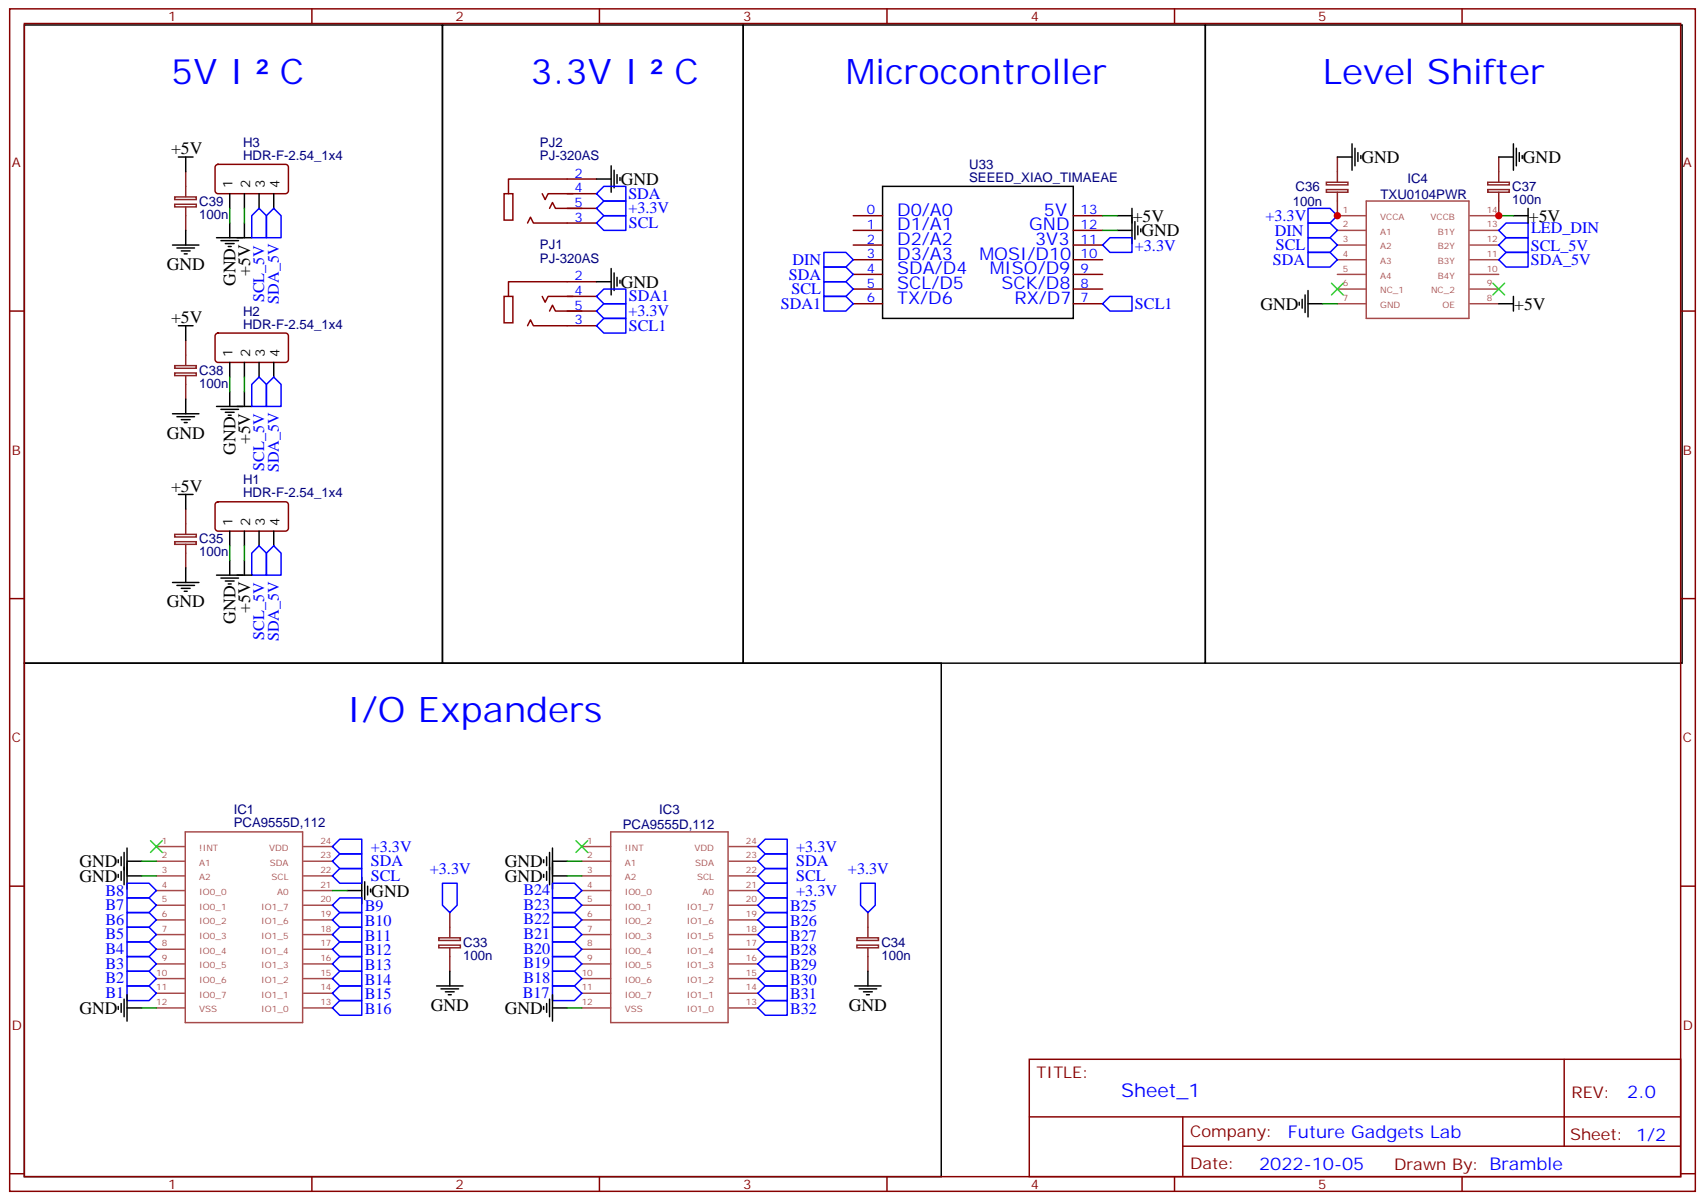
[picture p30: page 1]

Company: Future Gadgets Lab

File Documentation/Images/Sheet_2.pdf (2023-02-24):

A | A

1

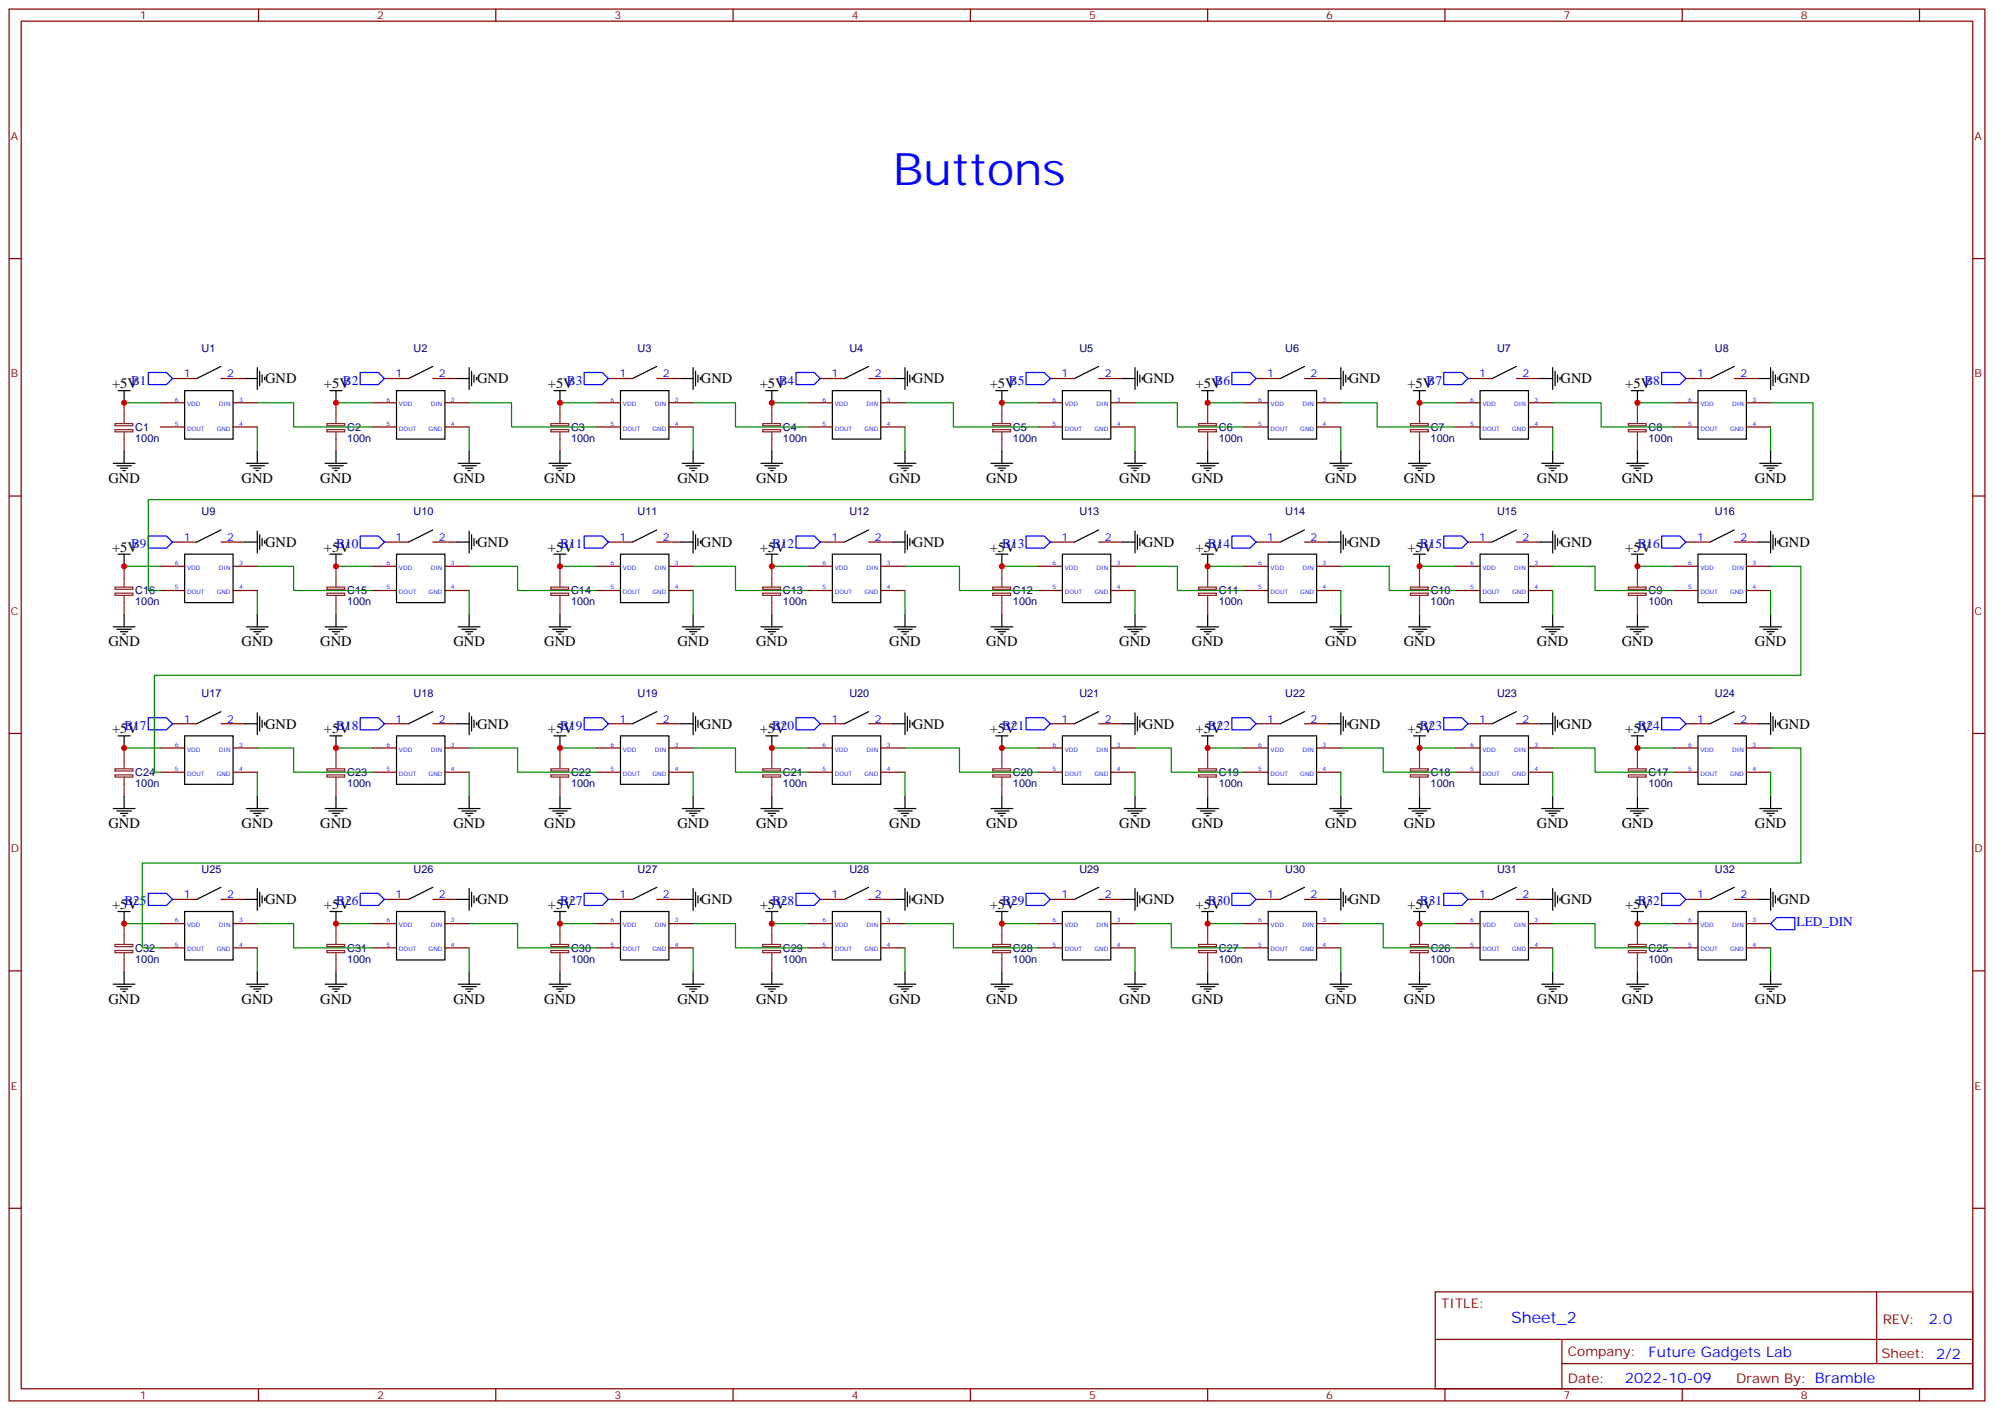
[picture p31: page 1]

Company: Future Gadgets Lab

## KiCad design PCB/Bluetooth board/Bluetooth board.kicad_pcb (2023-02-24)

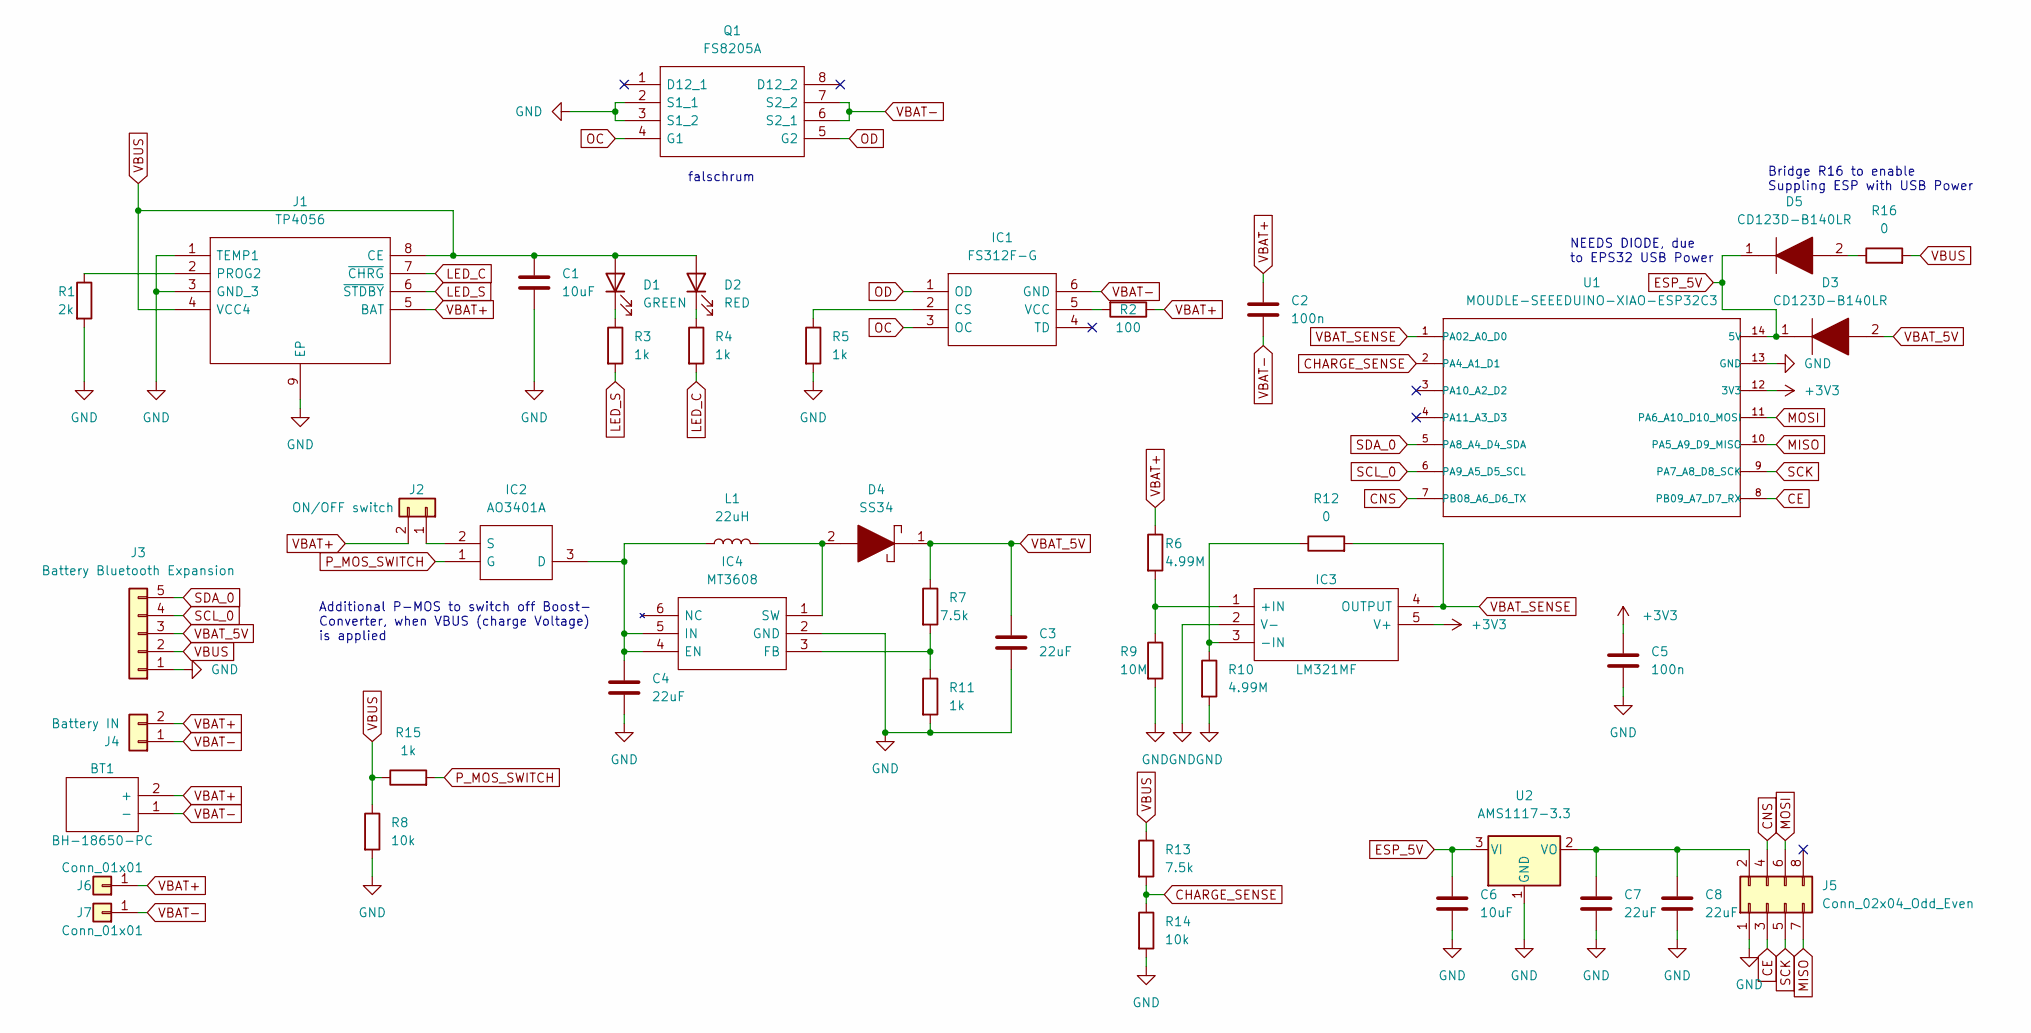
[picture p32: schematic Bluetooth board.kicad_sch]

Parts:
BT1: BH-18650-PC; BH18650PC; Manufacturer_Part_Number BH-18650-PC
C1, C6: 10uF; C_0603_1608Metric_Pad1.08x0.95mm_HandSolder; LCSC Part # C96446
C2, C5: 100n; C_0603_1608Metric_Pad1.08x0.95mm_HandSolder; LCSC Part # C14663
C3, C4, C7, C8: 22uF; C_1206_3216Metric_Pad1.33x1.80mm_HandSolder; LCSC Part # C12891
D1: GREEN; LED_D5.0mm
D2: RED; LED_D5.0mm
D3, D5: CD123D-B140LR; CD123DB140LR; Manufacturer_Part_Number CD123D-B140LR; Mouser Part Number 652-CD123D-B140LR
D4: SS34; D_SMA; Manufacturer_Part_Number SS34; Mouser Part Number 821-SS34
IC1: FS312F-G; SOT95P280X145-6N; Manufacturer_Part_Number FS312F-G; LCSC Part # C82736
IC2: AO3401A; SOT95P237X112-3N; Manufacturer_Part_Number IRLML6401; LCSC Part # C15127
IC3: LM321MF; SOT95P280X145-5N; Manufacturer_Part_Number LM321MF; Mouser Part Number 926-LM321MF
IC4: MT3608; SOT95P280X145-6N; Manufacturer_Part_Number MT3608; LCSC Part # C84817
J1: TP4056; SOIC127P600X175-9N; Manufacturer_Part_Number TP4056; LCSC Part # C16581
J2: ON/OFF switch; PinHeader_1x02_P2.54mm_Vertical
J3: Battery Bluetooth Expansion; PinSocket_1x05_P2.54mm_Vertical
J4: Battery IN; PinHeader_1x02_P2.54mm_Vertical
J5: Conn_02x04_Odd_Even; PinHeader_2x04_P2.54mm_Vertical
J6, J7: Conn_01x01; A FUCKING PAD
L1: 22uH; L_12x12mm_H6mm; LCSC Part # C2929501
Q1: FS8205A; SOP65P640X120-8N; Manufacturer_Part_Number FS8205A; LCSC Part # C16052
R1: 2k; R_0603_1608Metric_Pad0.98x0.95mm_HandSolder; LCSC Part # C22975
R2: 100; R_0603_1608Metric_Pad0.98x0.95mm_HandSolder; LCSC Part # C22775
R3, R4, R5, R11, R15: 1k; R_0603_1608Metric_Pad0.98x0.95mm_HandSolder; LCSC Part # C21190
R6, R10: 4.99M; R_0603_1608Metric_Pad0.98x0.95mm_HandSolder; LCSC Part # C158914
R7, R13: 7.5k; R_0603_1608Metric_Pad0.98x0.95mm_HandSolder; LCSC Part # C5140717
R8, R14: 10k; R_0603_1608Metric_Pad0.98x0.95mm_HandSolder; LCSC Part # C25804
R9: 10M; R_0603_1608Metric_Pad0.98x0.95mm_HandSolder; LCSC Part # C2907090
R12, R16: 0; R_0603_1608Metric_Pad0.98x0.95mm_HandSolder
U1: MOUDLE-SEEEDUINO-XIAO-ESP32C3; MOUDLE14P-SMD-2.54-21X17.8MM
U2: AMS1117-3.3; SOT-223-3_TabPin2; LCSC Part # C6186

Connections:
+3V3: C5.1, IC3.5 (V+), U1.12 (3V3)
CE: J5.3, U1.8 (PB09_A7_D7_RX)
CHARGE_SENSE: R13.2, R14.1, U1.2 (PA4_A1_D1)
CNS: J5.4, U1.7 (PB08_A6_D6_TX)
ESP_5V: C6.1, D3.1, D5.1, U1.14 (5V), U2.3 (VI)
GND: C1.2, C3.2, C4.2, C5.2, C6.2, C7.2, C8.2, IC3.2 (V-), IC4.2 (GND), J1.1 (TEMP1), J1.3 (GND_3), J1.9 (EP), J3.1, J5.1, Q1.2 (S1_1), Q1.3 (S1_2), R1.2, R5.2, R8.2, R9.2, R10.2, R11.2, R14.2, U1.13 (GND), U2.1 (GND)
LED_C: J1.7 (~CHRG), R4.2
LED_S: J1.6 (~STDBY), R3.2
MISO: J5.7, U1.10 (PA5_A9_D9_MISO)
MOSI: J5.6, U1.11 (PA6_A10_D10_MOSI)
unnamed: C4.1, IC2.3 (D), IC4.4 (EN), IC4.5 (IN), L1.1
unnamed: C7.1, C8.1, J5.2, U2.2 (VO)
unnamed: D1.1 (K), R3.1
unnamed: D2.1 (K), R4.1
unnamed: D4.2, IC4.1 (SW), L1.2
unnamed: D5.2, R16.1
unnamed: IC1.2 (CS), R5.1
unnamed: IC1.5 (VCC), R2.2
unnamed: IC2.2 (S), J2.1
unnamed: IC3.1 (+IN), R6.2, R9.1
unnamed: IC3.3 (-IN), R10.1, R12.1
unnamed: IC4.3 (FB), R7.2, R11.1
unnamed: J1.2 (PROG2), R1.1
OC: IC1.3 (OC), Q1.4 (G1)
OD: IC1.1 (OD), Q1.5 (G2)
P_MOS_SWITCH: IC2.1 (G), R15.2
SCK: J5.5, U1.9 (PA7_A8_D8_SCK)
SCL_0: J3.4, U1.6 (PA9_A5_D5_SCL)
SDA_0: J3.5, U1.5 (PA8_A4_D4_SDA)
VBAT+: BT1.2 (+), C2.1, J1.5 (BAT), J2.2, J4.2, J6.1, R2.1, R6.1
VBAT-: BT1.1 (-), C2.2, IC1.6 (GND), J4.1, J7.1, Q1.6 (S2_1), Q1.7 (S2_2)
VBAT_5V: C3.1, D3.2, D4.1, J3.3, R7.1
VBAT_SENSE: IC3.4 (OUTPUT), R12.2, U1.1 (PA02_A0_D0)
VBUS: C1.1, D1.2 (A), D2.2 (A), J1.4 (VCC4), J1.8 (CE), J3.2, R8.1, R13.1, R15.1, R16.2

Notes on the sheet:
falschrum
Bridge R16 to enable Suppling ESP with USB Power
NEEDS DIODE, due to EPS32 USB Power
Additional P-MOS to switch off Boost- Converter, when VBUS (charge Voltage) is applied

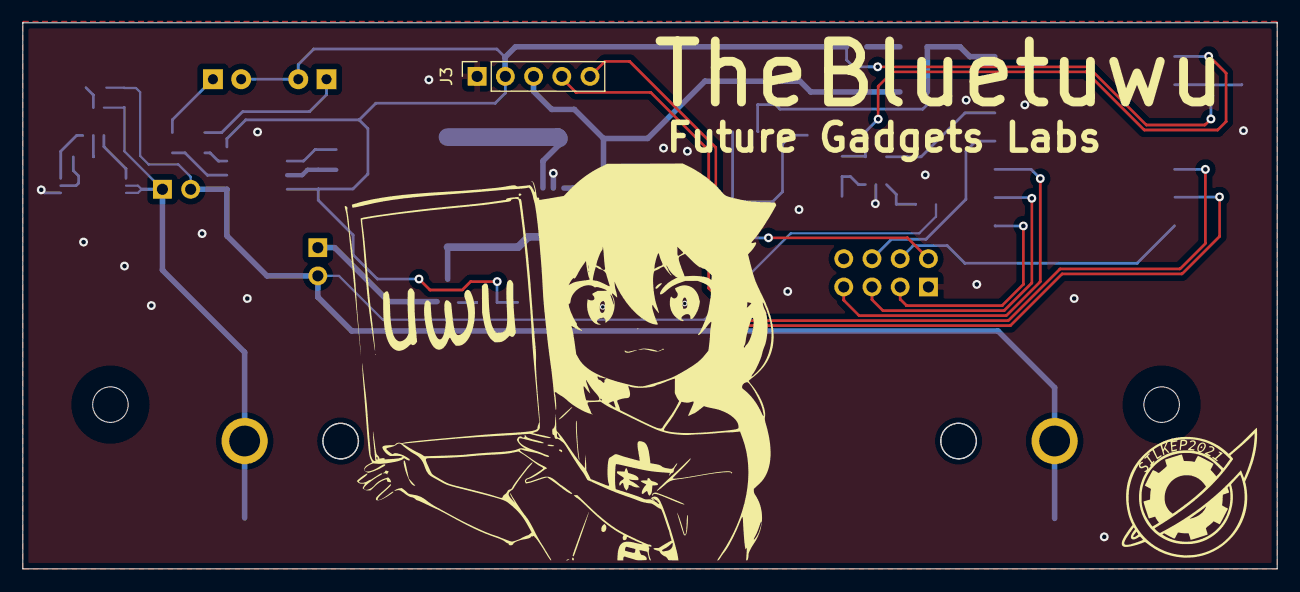
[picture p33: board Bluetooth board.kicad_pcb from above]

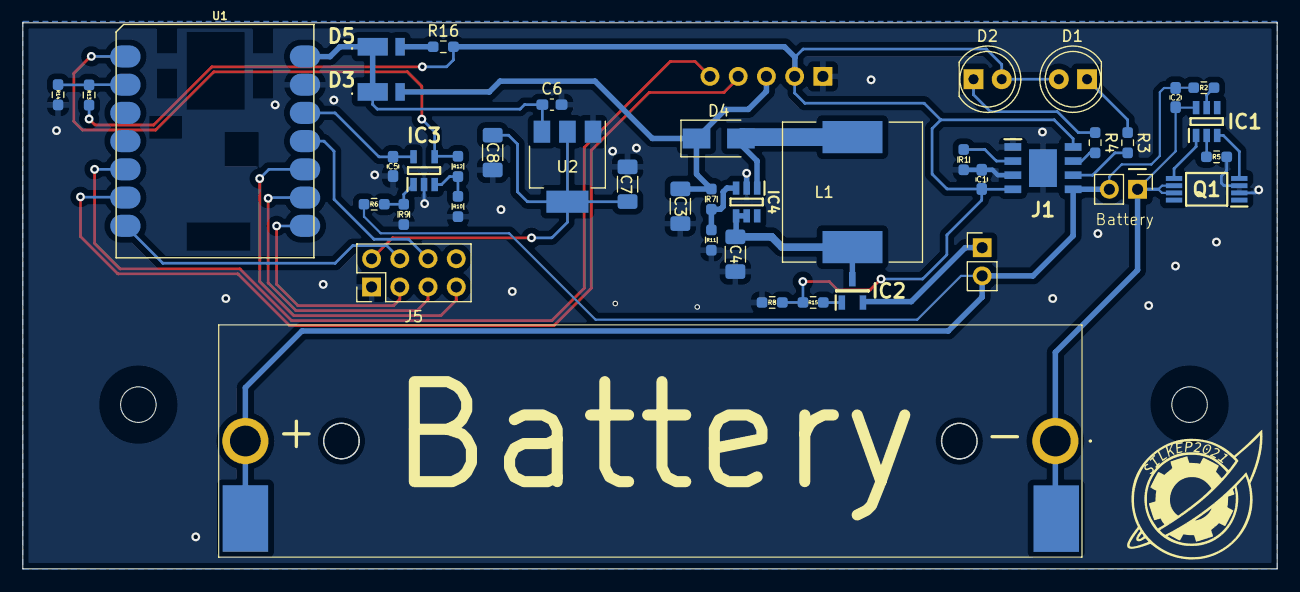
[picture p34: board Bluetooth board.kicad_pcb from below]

Board: 2 copper layers, 112.9 x 49.1 mm, 45 parts (44 on the bottom side), 34 nets.

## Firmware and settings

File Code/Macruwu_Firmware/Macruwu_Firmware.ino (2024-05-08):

#include "modules.h"
#include "hidInterface.h"
#include "lighting.h"
#include "i2cinterface.h"

//#define SERIAL_DEBUG


/////////////////////////////////////////////// Choose your base ///////////////////////////////////////////////
#define IS_MACRUWU
//#define IS_KEYBOARD


#define MACRUWU_VERSION 2

#define ADDRESS_NUMPAD1 0x20
#define ADDRESS_Bluetooth 0x69

uint8_t registered_I2C_addresses[] = {ADDRESS_NUMPAD1,ADDRESS_Bluetooth};

#ifdef IS_MACRUWU
_macruwu macruwu("macruwu", MACRUWU_VERSION);
RGB_LIGHTING lighting_macruwu(29, 32, 50);    // RGB_LIGHTING(uint8_t led_pin, uint16_t led_count, uint8_t led_max_brightness)
#endif

#ifdef IS_KEYBOARD
RGB_LIGHTING lighting_keyboard(1, 88, 50);    // RGB_LIGHTING(uint8_t led_pin, uint16_t led_count, uint8_t led_max_brightness)
_keyboard keyboard("keyboard");
_numpad numpad1("numpad1", ADDRESS_NUMPAD1);
#endif

i2cInterface i2c(registered_I2C_addresses, sizeof(registered_I2C_addresses));
hidInterface hid(1000, ADDRESS_Bluetooth);

uint64_t prev;
uint8_t error;


void setup() {
  Serial.begin(115200);
  Serial.println("uwu Setup 1");

  filesystemSetup();
  Serial.println("uwu Setup 2");

  filesystemCreateConfig();
  Serial.println("uwu Setup 3");

  hid.init();

  Serial.println("uwu Setup 4");

  Serial.println("uwu Setup 5");

  i2c.init();     // REMEMBER: if you update the files, you need to disable the setting of the i2C pins. This will cause the controller to crash

  #ifdef IS_KEYBOARD
  lighting_keyboard.setup();
  lighting_keyboard.set_led_remap(keyboard.get_led_remap(), keyboard.get_ammount_keys());
  keyboard.init();
  numpad1.init(&i2c);
  #endif

  #ifdef IS_MACRUWU
  macruwu.init(); // Dependant on I2C!! Call after i2c.init()!!
  macruwu.updateKeymapsFromFile();
  lighting_macruwu.setup();
  lighting_macruwu.set_led_remap(macruwu.get_led_remap(), macruwu.get_ammount_keys());
  
  #endif

  if(hid.bluetooth_mode == 0){
    error = i2c.disableESP(ADDRESS_Bluetooth);
  }

  prev = 0;
}



/////////////////////////////////////////////////////////////// Loop ///////////////////////////////////////////////////////////////

void loop() {

  check_fs_update();

  scanI2C();

  #ifdef IS_KEYBOARD
  lighting_keyboard.update();
  lighting_keyboard.set_effect(keyboard.getLayerLightingEffect());

  handleKeyboard();
  handleNumpad();
  #endif

  #ifdef IS_MACRUWU
  lighting_macruwu.update();
  lighting_macruwu.set_effect(macruwu.getLayerLightingEffect());

  handleMacruwu();
  #endif

  hid.clear_midi_CC_update_available();

  while(hid.readMidi()) hid.readMidi();
  delay(1);
}

/////////////////////////////////////////////////////////////// Macruwu Handler ///////////////////////////////////////////////////////////////
#ifdef IS_MACRUWU
inline void handleMacruwu(){
  macruwu.update();

  for(int i = 0; i < 32; i++){
    key *currentKey = macruwu.getKeyPointer(i + 1);

    if(currentKey->color_mode == midi_bound && hid.get_midi_CC_update_available(currentKey)){
      if(hid.get_midi_CC_state(currentKey) ){
        lighting_macruwu.enable_override(i, currentKey->color);
        hid.set_midi_CC_update_handled(currentKey);
      }
      else {
        lighting_macruwu.disable_override(i);
        hid.set_midi_CC_update_handled(currentKey);
      }
    }

    if(macruwu.isPressed(i)){
      if(currentKey->hasLayerChange) macruwu.setLayer(currentKey->changeToLayer);
      
      if(currentKey->isMIDI) hid.sendMidi_Analog(macruwu.getKeyPointer(i + 1), 255);
      
      else Serial.printf("pressing index: %d\n", i); hid.press(currentKey);
      
      switch(currentKey->color_mode){
        case no_override: break;
        case midi_bound: break;
        case pressed: lighting_macruwu.enable_override(i, currentKey->color); break;
        case not_pressed: lighting_macruwu.disable_override(i); break;
        case toggle: lighting_macruwu.toggle_override(i, currentKey->color); break;
        case disabled: lighting_macruwu.disable_override(i); break;
      }
    }
    else if(macruwu.isReleased(i)){
      if(currentKey->isMIDI) hid.sendMidi_Analog(macruwu.getKeyPointer(i + 1), 0);
      
      else Serial.println("releasing"); hid.release(macruwu.getKeyPointer(i + 1));
      

      switch(currentKey->color_mode){
        case no_override: break;
        case midi_bound: break;
        case pressed: lighting_macruwu.disable_override(i); break;
        case not_pressed: lighting_macruwu.enable_override(i, currentKey->color); break;
        case toggle: break;
        case disabled: lighting_macruwu.disable_override(i); break;
      }
    }
  }
}
#endif

/////////////////////////////////////////////////////////////// Keyboard Handler ///////////////////////////////////////////////////////////////
#ifdef IS_KEYBOARD
inline void handleKeyboard(){
  keyboard.update();

  for(int i = 0; i < AMMOUNT_KEYS; i++){
    key *currentKey = keyboard.getKeyPointer(i + 1);

    if(currentKey->color_mode == midi_bound && hid.get_midi_CC_update_available(currentKey)){
      if(hid.get_midi_CC_state(currentKey)){
        lighting_keyboard.enable_override(i, currentKey->color);
        hid.set_midi_CC_update_handled(currentKey);
      }
      else {
        hid.set_midi_CC_update_handled(currentKey);
        lighting_keyboard.disable_override(i);
      }
    }

    if(currentKey->color_mode == const_color) lighting_keyboard.enable_override(i, currentKey->color);

    if(currentKey->color_mode == disabled) lighting_keyboard.enable_override(i, 0);

    if(keyboard.isPressed(i)){
      if(currentKey->hasLayerChange) keyboard.setLayer(currentKey->changeToLayer);

      if(currentKey->isMIDI) hid.sendMidi_Analog(keyboard.getKeyPointer(i + 1), 255);
      
      else Serial.println("pressing"); hid.press(currentKey);
      
      switch(currentKey->color_mode){
        case no_override: break;
        case midi_bound: break;
        case pressed: lighting_keyboard.enable_override(i, currentKey->color); break;
        case not_pressed: lighting_keyboard.disable_override(i); break;
        case toggle: lighting_keyboard.toggle_override(i, currentKey->color); break;
        case disabled: lighting_keyboard.disable_override(i); break;
      }
    }
    else if(keyboard.isReleased(i)){
      if(currentKey->isMIDI) hid.sendMidi_Analog(keyboard.getKeyPointer(i + 1), 0);
      
      else Serial.println("releasing"); hid.release(keyboard.getKeyPointer(i + 1));

      switch(currentKey->color_mode){
        case no_override: break;
        case midi_bound: break;
        case pressed: lighting_keyboard.disable_override(i); break;
        case not_pressed: lighting_keyboard.enable_override(i, currentKey->color); break;
        case toggle: break;
        case disabled: lighting_keyboard.disable_override(i);
      }
    }
  }
}
#endif

/////////////////////////////////////////////////////////////// Numpad Handler ///////////////////////////////////////////////////////////////

#ifdef IS_KEYBOARD
inline void handleNumpad(){
  
  numpad1.update();

  if(numpad1.registered()){
    for(int i = 0; i < I2C_BUFFER_SIZE; i++){
      key *currentKey = numpad1.getKeyPointer(i + 1);
      if(currentKey == nullptr) continue;

      // Key color handler
      if(currentKey->color_mode == midi_bound && hid.get_midi_CC_update_available(currentKey)){
        if (hid.get_midi_CC_state(currentKey)) {
          i2c.send_led_override_update(numpad1.address(), numpad1.remap_led_key(i), true);
          hid.set_midi_CC_update_handled(currentKey);
        }
        else {
          i2c.send_led_override_update(numpad1.address(), numpad1.remap_led_key(i), false);
          hid.set_midi_CC_update_handled(currentKey);
        }
      }

      // Update Fader values
      if(currentKey->isMIDI && currentKey->isAnalog){         //don't forget to compare val with previous val when setting. Yes mum...
        hid.sendMidi_Analog(numpad1.getKeyPointer(i + 1), map(i2c.getVal(i + 1, numpad1.address()), 0, 255, 0, 127));
      }

      else if(numpad1.isPressed_hold(i)){
        if(currentKey->hasLayerChange){
          numpad1.setLayer(currentKey->changeToLayer);
        }
        if(currentKey->isMIDI){
          hid.sendMidi_Digital(numpad1.getKeyPointer(i + 1), true);
        }
        else{
          Serial.println("pressing");
          hid.press(numpad1.getKeyPointer(i + 1));
        }
        switch(currentKey->color_mode){
          case no_override: break;
          case midi_bound: break;
          case pressed: i2c.send_led_override_update(numpad1.address(), numpad1.remap_led_key(i), true); break;
          case not_pressed: i2c.send_led_override_update(numpad1.address(), numpad1.remap_led_key(i), false); break;
          case toggle: i2c.send_led_override_update(numpad1.address(), numpad1.remap_led_key(i), false); break;
          case disabled: i2c.send_led_override_update(numpad1.address(), numpad1.remap_led_key(i), false); break;
        }
      }
      else if(numpad1.isReleased_hold(i)){
        if(currentKey->isMIDI) hid.sendMidi_Digital(numpad1.getKeyPointer(i + 1), false);

        else Serial.println("releasing"); hid.release(numpad1.getKeyPointer(i + 1));

        switch(currentKey->color_mode){
          case no_override: break;
          case midi_bound: break;
          case pressed: i2c.send_led_override_update(numpad1.address(), numpad1.remap_led_key(i), false); break;
          case not_pressed: i2c.send_led_override_update(numpad1.address(), numpad1.remap_led_key(i), true); break;
          case toggle: break;
          case disabled: i2c.send_led_override_update(numpad1.address(), numpad1.remap_led_key(i), false); break;
        }
      }
      
    }
  }
}
#endif

/////////////////////////////////////////////////////////////// I2C scanner ///////////////////////////////////////////////////////////////

inline void scanI2C(){
  if(millis() > prev + 1000){
    prev = millis();
    #ifdef IS_KEYBOARD
    i2c.probe();
    #endif
    #ifdef SERIAL_DEBUG
      Serial.println("uwu");
      if(error == 0) Serial.println("ESP disabled successfully");
      else Serial.print("ESP has given error on disable: ");Serial.println(error);
    #endif
  }
}


/////////////////////////////////////////////////////////////// Filesystem Update Handler ///////////////////////////////////////////////////////////////

inline void check_fs_update(){
  if(check_fs_changed()){
    #ifdef IS_KEYBOARD
    keyboard.updateKeymapsFromFile();
    numpad1.updateKeymapsFromFile();
    for(int i = 0; i < numpad1.ammountKeys; i++){
      key *currentKey = numpad1.getKeyPointer(i);
      if(currentKey->color_mode != no_override){
        i2c.set_led_override(numpad1.address(), numpad1.remap_led_key(i), currentKey->color);
      }
    }
    #endif

    #ifdef IS_MACRUWU
    macruwu.updateKeymapsFromFile();
    Serial.printf("current Layer: %d\n", macruwu.current_layer);
    #endif

    
    
    set_fs_changed(false);
  }
}

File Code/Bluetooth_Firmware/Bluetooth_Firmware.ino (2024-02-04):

/**
 * if Stuff no work, check this: https://github.com/T-vK/ESP32-BLE-Keyboard/issues/169
 * 
 * for compiling settings see README.md
 */
#include "BleKeyboard.h"
#include <Wire.h>
#include <memory>
#include "esp_bt.h"

//#define BAT_V_PIN 2
//#define PIN_SDA 6
//#define PIN_SCL 7

#define ADDR_I2C 0x69
#define DELAY_FOR_GET_BATTERY_LEVEL 10000

enum
{
  RID_KEYBOARD = 1,
  RID_GAMEPAD,
  RID_CONSUMER_CONTROL, // Media, volume etc ..
};

BleKeyboard bleKeyboard("Macruwu", "FG Labs", 69);

uint8_t delayTime = 60;
uint64_t time_prev = 0;

bool softDisableFlag = 0;

String sendString;
//KeyReport reportBuffer;
std::vector <KeyReport *> reportBuffer;

void Keyboard_print(String text);
void Keyboard_send_buffer();
void clear_send_buffer();
void receiveEvent(int howMany);

void setup() {
  Serial.begin(115200);
  Serial.println("Starting BLE work!");
  bleKeyboard.begin();
  bleKeyboard.setBatteryLevel(get_battery_level());
  //Wire.setPins(PIN_SDA, PIN_SCL);
  Wire.begin(ADDR_I2C);
  Wire.onReceive(receiveEvent);
  time_prev = millis();
}



void loop() {
  if(bleKeyboard.isConnected() && reportBuffer.size() > 0) {
    Keyboard_send_buffer();
  }
  else if(reportBuffer.size() > 0){
    for(int i = 0; i < reportBuffer.size(); i++){
      delete reportBuffer.at(i);          //prevent memory leaks (hopefully...)
    }
    reportBuffer.clear();
  }

  if(millis() > (time_prev + DELAY_FOR_GET_BATTERY_LEVEL)){
    time_prev = millis();
    bleKeyboard.setBatteryLevel(get_battery_level());
    Serial.println("Updated  Battery level");
  }

  if(softDisableFlag){
    esp_bt_controller_disable();
    esp_deep_sleep_start();
    //while(softDisableFlag) delay(100);
  }

}

void receiveEvent(int howMany){
  reportBuffer.push_back(new KeyReport);
  KeyReport *tmp = reportBuffer.at(reportBuffer.size()-1);
  uint8_t reportID = 0;
  while(Wire.available()){
    reportID = Wire.read();
    switch(reportID){
      case RID_KEYBOARD:
        tmp->modifiers = Wire.read();
        tmp->keys[0] = Wire.read();
        tmp->keys[1] = Wire.read();
        tmp->keys[2] = Wire.read();
        tmp->keys[3] = Wire.read();
        tmp->keys[4] = Wire.read();
        tmp->keys[5] = Wire.read();
        break;
      case 15:
        softDisableFlag = Wire.read();
        if(softDisableFlag != 0) softDisableFlag = true;
        break;
      default:
        Wire.read();
        break;
    }
    // Read in format ReportID,modifier,keycodes[6]
  }
}

void Keyboard_send_buffer(){
  Serial.println("Sending Buffer");
  for(int i = 0; i < reportBuffer.size(); i++){
    if((i%4)==0 && i > 0){
      delay(delayTime);
    }
    bleKeyboard.sendReport(reportBuffer.at(i));
    //bleKeyboard.releaseAll();
    for(int n = 0; n < 6; n++){
      Serial.print(reportBuffer.at(i)->keys[n]);
    }
    Serial.println(reportBuffer.at(i)->modifiers);
  }

  for(int i = 0; i < reportBuffer.size(); i++){
    delete reportBuffer.at(i);          //prevent memory leaks (hopefully...)
  }
  reportBuffer.clear();
}

uint8_t get_battery_level(){        // Disabled for Macruwu because of error in Board design
  return 69;
  //return (uint8_t)map(analogRead(BAT_V_PIN), 0, 1023, 0, 100);
}

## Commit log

2024-02-04 ported firmware from Typeuwu. (it's a lot better now...)
    [Base no battery.SLDASM, Part1 no headphone.STL, Part1.SLDPRT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]
2024-05-08 fixed buig with I2C
    [Macruwu_Firmware.ino, i2cinterface.cpp]
